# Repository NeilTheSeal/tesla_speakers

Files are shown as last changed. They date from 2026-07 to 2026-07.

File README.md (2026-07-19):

# Tesla Model 3 Rear-Cabin Speaker

A parametric, 3D-printable sealed speaker enclosure for the rear cabin floor behind the center console of a Tesla Model 3. The cabinet is modeled in [CodeCAD](https://codecad.xyz/) with Lua and designed for active DSP (woofer channel) and passive crossover (midrange/tweeter channel) use with the vehicle's 65W/4Ω amplifier outputs.

**Current System:** 3-driver mono loudspeaker (woofer + midrange + tweeter) with sealed chambers and removable, gasketed service panels for future modifications.

**Current Phase:** Fabrication readiness: inventory delivered hardware, commission the printer, and verify physical dimensions before revising or printing the enclosure.

For comprehensive project documentation, see the `docs/` folder: [PROJECT.md](docs/PROJECT.md), [REQUIREMENTS.md](docs/REQUIREMENTS.md), [WORK_HISTORY.md](docs/WORK_HISTORY.md), and [HARDWARE_SPECS.md](docs/HARDWARE_SPECS.md).

## Renders

Generated cabinet model:

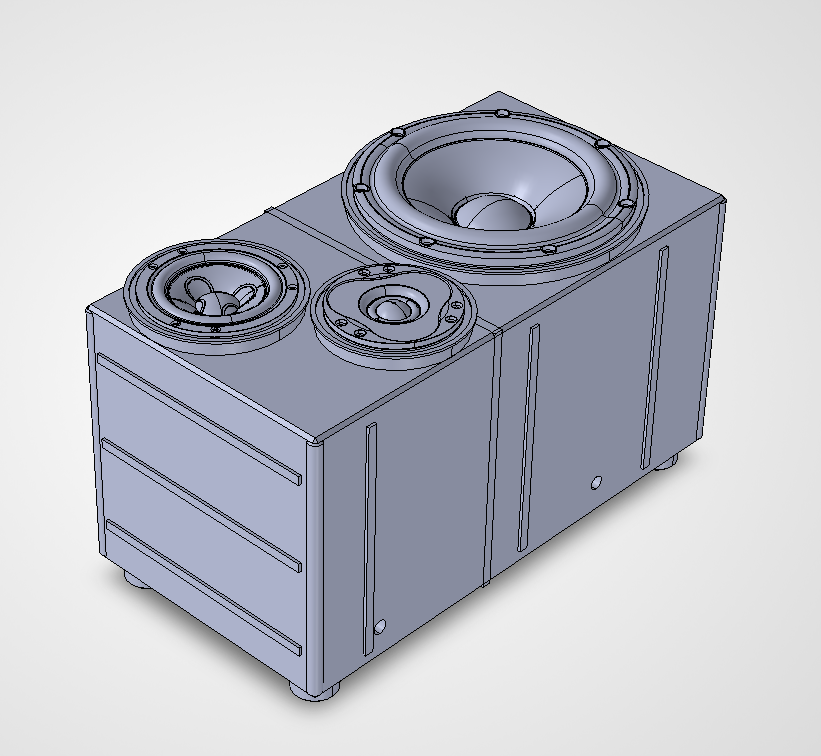
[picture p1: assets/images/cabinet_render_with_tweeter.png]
Cabinet render


## Drivers

| Position | Driver | Impedance | Status |
| --- | --- | --- | --- |
| Woofer | Scan-Speak Revelator 22W/4851T00 | 4 Ω | Purchased |
| Midrange | Scan-Speak Illuminator 12MU/4731T00 | 4 Ω | Purchased |
| Tweeter  | Scan-Speak Illuminator D3004/662000 | 4 Ω | Working selection (verification pending) |

**Driver mounting:** Cutout sizes and frame dimensions are encoded in [parts/part.lua](parts/part.lua) and must be verified against physical drivers before a full-size print.

## Current Design

**System Architecture:**

- **Amplifier channel 1** → DSP low-pass + tuning → Woofer (dedicated sealed chamber)
- **Amplifier channel 2** → DSP high-pass + tuning → Passive midrange/tweeter crossover
  - Midrange and tweeter share the second amplifier output through a passive network
  - Crossover frequency: ~2.5 kHz (provisional, subject to measurement)

**Enclosure:**

- Sealed, two-chamber cabinet (separate woofer and midrange volumes) with isolated tweeter rear chamber
- Primarily one-piece large-format 3D-printed structural shell
- Removable, gasketed side-access panels for service access and future modifications
- Internal divider isolates midrange from woofer back-wave pressure
- Nominal dimensions: 241.3 mm (width) × 410 mm (length) × 220 mm (height)
- Generated STL envelope: 246.3 mm × 415 mm × 253.05 mm (preliminary)
- Preliminary chamber volumes: woofer ~12.04 L, midrange ~5.70 L (awaiting detailed analysis)

**Structural Features:**

- 8 mm enclosure walls with internal bracing and reinforcement ribs
- 12 mm raised driver baffles with trim rings
- Internal woofer chamber window brace with rounded opening
- Two 12.5 mm side-wall wire pass-throughs (sized for PG7 cable glands)
- Four Sorbothane-ready isolation feet (38.1 mm diameter, 19.05 mm tall)
- Flared foot collars and underside X cross-bracing for stiffness
- Low-relief exterior detail elements

**Current Milestone:** Complete one documented printer calibration print, then verify the physical drivers and vehicle envelope. The removable, gasketed side panel remains the next focused CAD revision; no full enclosure print should begin until those gates and feature coupons pass.

## Files

- `assets/` — Cabinet and assembly renders, reference CAD models
- `docs/` — Project documentation (PROJECT.md, REQUIREMENTS.md, WORK_HISTORY.md, HARDWARE_SPECS.md)
- `parts/` — Parametric CodeCAD model (part.lua)
- `scripts/` — Utility scripts
- `generated/` — Build outputs (STL and STEP files)
- `.claude/` — Claude Code configuration and project instructions (CLAUDE.md)
- `.obsidian/` — Obsidian vault configuration and settings
- `.luarc.json` — Lua language server configuration for IDE support
- `project.json` — CodeCAD project definition
- `AGENTS.md` — AI agent coordination and workflow documentation
- `imgui.ini` — CodeCAD ImGui layout and window state

## Build

This project uses millimeters. Install CodeCAD, then run these commands from
the repository root:

```bash
# Open CodeCAD's live viewer and reload the model on each save.
ccad live

# Export STL and STEP files to generated/.
ccad build

# Check the CodeCAD installation if needed.
ccad doctor
```

## Parameters

The editable values are grouped at the top of
[parts/part.lua](parts/part.lua). The most useful groups are:

- **Cabinet:** width, length, height, wall thickness, divider location, and
  window-brace dimensions.
- **Drivers:** cutout sizes, frame sizes, bolt geometry, and individual X/Y
  positions.
- **Isolation:** foot dimensions, collar flare, Sorbothane pocket, and bottom
  cross-brace dimensions.
- **Finish:** baffle trim rings, exterior rails, corner bumpers, and the
  recessed monogram badge.

All driver-related position changes move the baffle, main cutout, and its bolt
pattern together.

## Print And Assembly Notes

- Use this PLA+ design as a functional prototype. For sustained in-car use,
  prefer a higher-temperature material such as ASA, PETG, or another material
  appropriate to the vehicle's temperature range.
- Use closed-cell gasket tape under the driver frames and seal the wire exits
  with suitable grommets and flexible sealant. A sealed cabinet is sensitive to
  small air leaks.
- Fit 1.0625 in diameter by 0.25 in thick Sorbothane discs into the underside
  foot pockets. Select the Sorbothane durometer for the fully loaded cabinet
  weight and intended compression range.
- Line the woofer chamber walls with damping material. Add stuffing gradually
  after measurement; keep it clear of the woofer basket and vent.
- Line and moderately fill the isolated midrange chamber with suitable acoustic
  absorption to reduce internal reflections.
- The model includes structural braces, but print orientation, perimeter count,
  material choice, and infill should be chosen for a rigid, airtight enclosure.

## Status

This is a proof-of-concept enclosure intended for active tuning and in-car
measurement. Validate the final response, crossover settings, sealing, and
mechanical fit with the actual drivers before treating it as a permanent
installation. The printer, speakers, filament, tools, and related supplies have
been reported as delivered, but exact inventory and commissioning results are
not yet recorded. The immediate sequence is inventory → printer calibration →
physical driver and vehicle checks → focused feature coupons → full-print review.

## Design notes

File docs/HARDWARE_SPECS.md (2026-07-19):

---
document: HARDWARE_SPECS
project: Tesla Rear-Cabin Speaker
status: Reference
version: 0.1
last_updated: 2026-07-18
---

# Tesla Rear-Cabin Speaker - Hardware Specifications

## 1. Purpose and source status

This file is a convenient Markdown transcription of manufacturer specifications for the three intended Scan-Speak drivers. It is a reference, not a replacement for the original datasheets or physical measurements.

Primary sources:

- [Scan-Speak Illuminator 12MU/4731T00 datasheet](../assets/datasheets/12mu-4731t00.pdf)
- [Scan-Speak Revelator 22W/4851T00 datasheet](../assets/datasheets/22w-4851t00.pdf)
- [Scan-Speak Illuminator D3004/662000 datasheet](../assets/datasheets/d3004-662000.pdf)

Important interpretation rules:

- Manufacturer values describe representative production units under the manufacturer's test conditions.
- Nominal impedance is not a fixed resistance; actual impedance varies with frequency.
- Manufacturer response curves are useful design references but do not represent the response of these particular units in the project enclosure or vehicle.
- Manufacturer enclosure recommendations are examples, not automatically the correct alignments for this project.
- Physical driver dimensions, DC resistance, mounted response, and impedance shall still be measured or verified before the design is frozen.

## 2. Driver summary

| Role | Driver | Nominal impedance | Sensitivity (2.83 V/1 m) | Recommended operating range | Linear excursion |
| --- | --- | ---: | ---: | ---: | ---: |
| Midrange | Scan-Speak Illuminator 12MU/4731T00 | 4 ohm | 90 dB | 100-10,000 Hz | +/- 3.5 mm |
| Woofer | Scan-Speak Revelator 22W/4851T00 | 4 ohm | 89 dB | fs-3,000 Hz | +/- 9 mm |
| Tweeter  | Scan-Speak Illuminator D3004/662000 | 4 ohm | 91.5 dB | 2,500-30,000 Hz | +/- 0.2 mm |

The sensitivity figures are not sufficient by themselves to set final relative levels. Baffle geometry, measurement distance, crossover losses, frequency-dependent response, and the vehicle installation will affect the required DSP and passive-network attenuation.

---

# 3. Scan-Speak Illuminator 12MU/4731T00 midrange

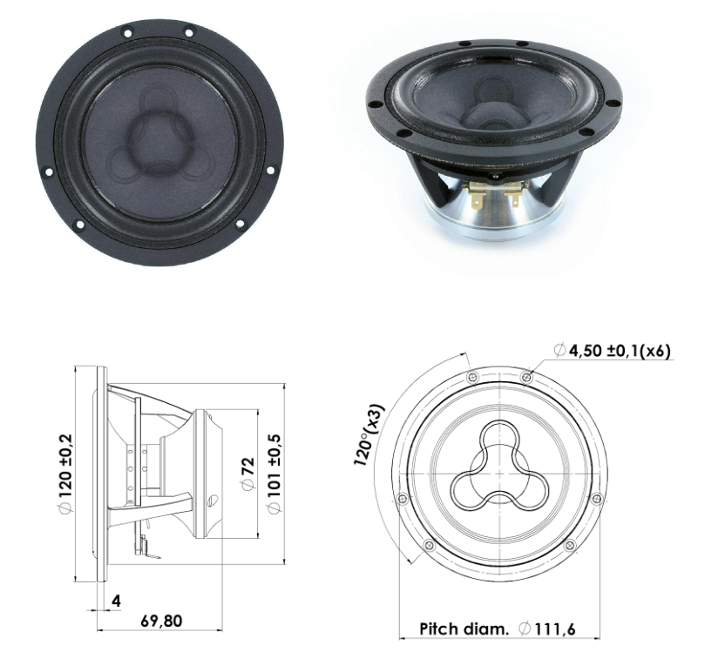
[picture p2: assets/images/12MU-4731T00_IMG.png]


## 3.1 Thiele-Small parameters

| Parameter | Symbol | Value |
| --- | --- | ---: |
| Resonance frequency | fs | 64 Hz |
| Mechanical Q factor | Qms | 3.64 |
| Electrical Q factor | Qes | 0.26 |
| Total Q factor | Qts | 0.24 |
| Force factor | Bl | 5.1 Tm |
| Mechanical resistance | Rms | 0.60 kg/s |
| Moving mass | Mms | 5.4 g |
| Compliance | Cms | 1.15 mm/N |
| Effective diaphragm diameter | D | 86 mm |
| Effective piston area | Sd | 58 cm^2 |
| Equivalent compliance volume | Vas | 5.4 L |
| Sensitivity | - | 90 dB at 2.83 V/1 m |

## 3.2 Mechanical data

| Parameter | Value |
| --- | ---: |
| Voice-coil diameter | 32 mm |
| Voice-coil height | 6 mm |
| Voice-coil layers | 4 |
| Gap height | 13 mm |
| Linear excursion | +/- 3.5 mm |
| Maximum mechanical excursion |  +/- 10 mm |
| Unit weight | 0.8 kg |
| Cabinet displacement volume  | 0.14 L |

## 3.3 Electrical data

| Parameter | Symbol | Value |
| --- | --- | ---: |
| Nominal impedance | Zn | 4 ohm |
| Minimum impedance | Zmin |  4.3 ohm |
| Maximum impedance | Zo | 46.5 ohm |
| DC resistance | Re |  3.1 ohm |
| Voice-coil inductance | Le |  0.11 mH |

## 3.4 Power handling

| Test or condition | Value |
| --- | ---: |
| 100-hour RMS noise test, IEC 18.4 | 80 W |
| Long-term maximum power, IEC 18.2 | 150 W |
| Manufacturer test crossover | Second-order Butterworth high-pass at 200 Hz |

The power ratings are tied to the manufacturer's stated test conditions. They do not mean the driver can safely dissipate those powers with arbitrary signals, enclosure loading, or filters.

## 3.5 Manufacturer-listed key features

- Under-hung neodymium motor design
- Patented Symmetrical Drive (SD-3)
- One-piece cone and dust cap
- Low-loss linear suspension
- Very wide 100-10,000 Hz frequency response
- 90 dB output at 2.83 V

## 3.6 Manufacturer recommendations

| Item | Recommendation |
| --- | --- |
| Operating frequency range | 100-10,000 Hz |
| Closed box example | Vbox = 0.9 L; f(-3 dB) = 172 Hz |
| Vented box example | Vbox = 1.5 L; fb = 99 Hz; f(-3 dB) = 119 Hz |

## 3.7 Manufacturer response and impedance curves

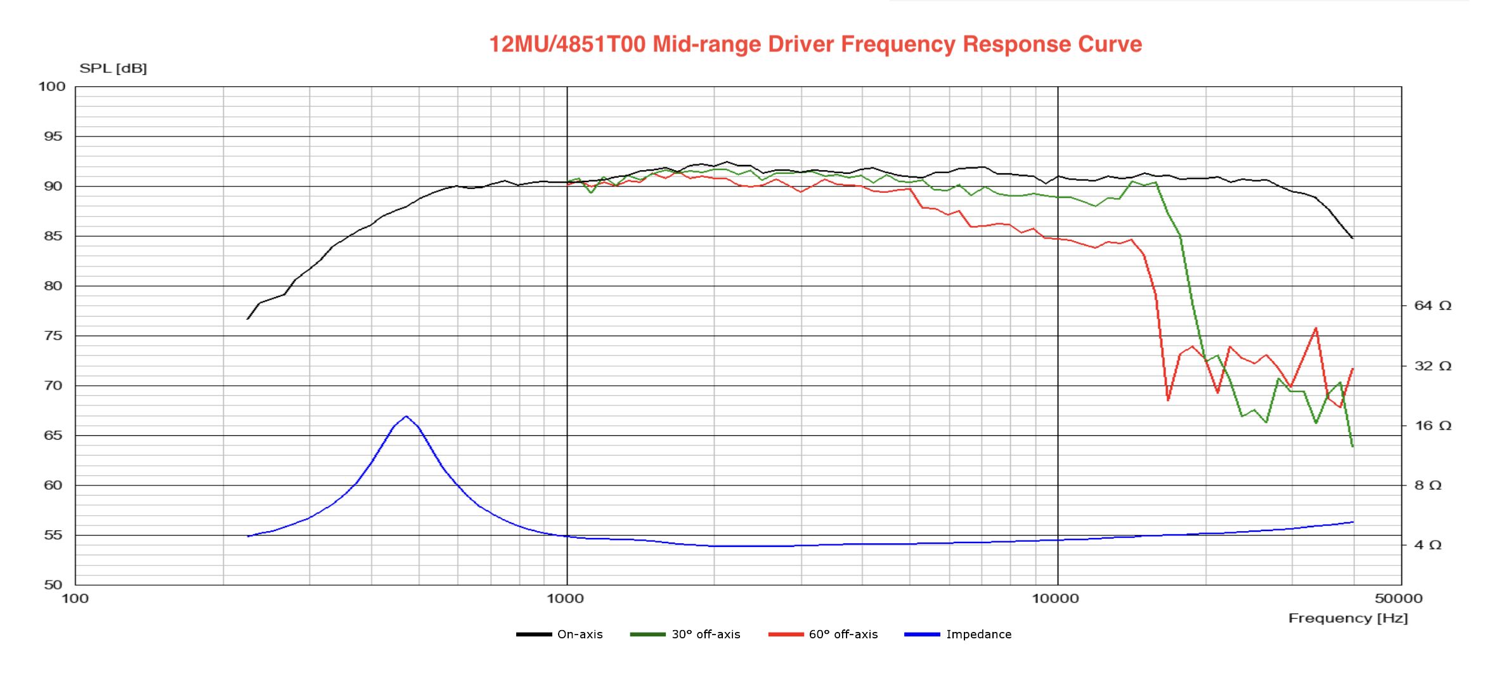
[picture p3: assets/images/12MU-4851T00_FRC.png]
12MU/4731T00 manufacturer response and impedance curves


Qualitative reading only:

- The on-axis response is broadly near 90 dB through much of the midrange and remains extended well above the intended approximate 2.5 kHz midrange/tweeter transition.
- The 30-degree and especially 60-degree curves fall progressively below the on-axis curve as frequency rises, showing the expected narrowing directivity of a cone driver.
- The impedance peak near the driver's resonance and the rising high-frequency impedance confirm that the driver cannot be treated as an ideal 4-ohm resistor during passive-crossover design.
- The smooth response around the provisional crossover region makes approximately 2.5 kHz a plausible starting region, but the final acoustic target must come from measurements in the actual baffle.

---

# 4. Scan-Speak Revelator 22W/4851T00 woofer

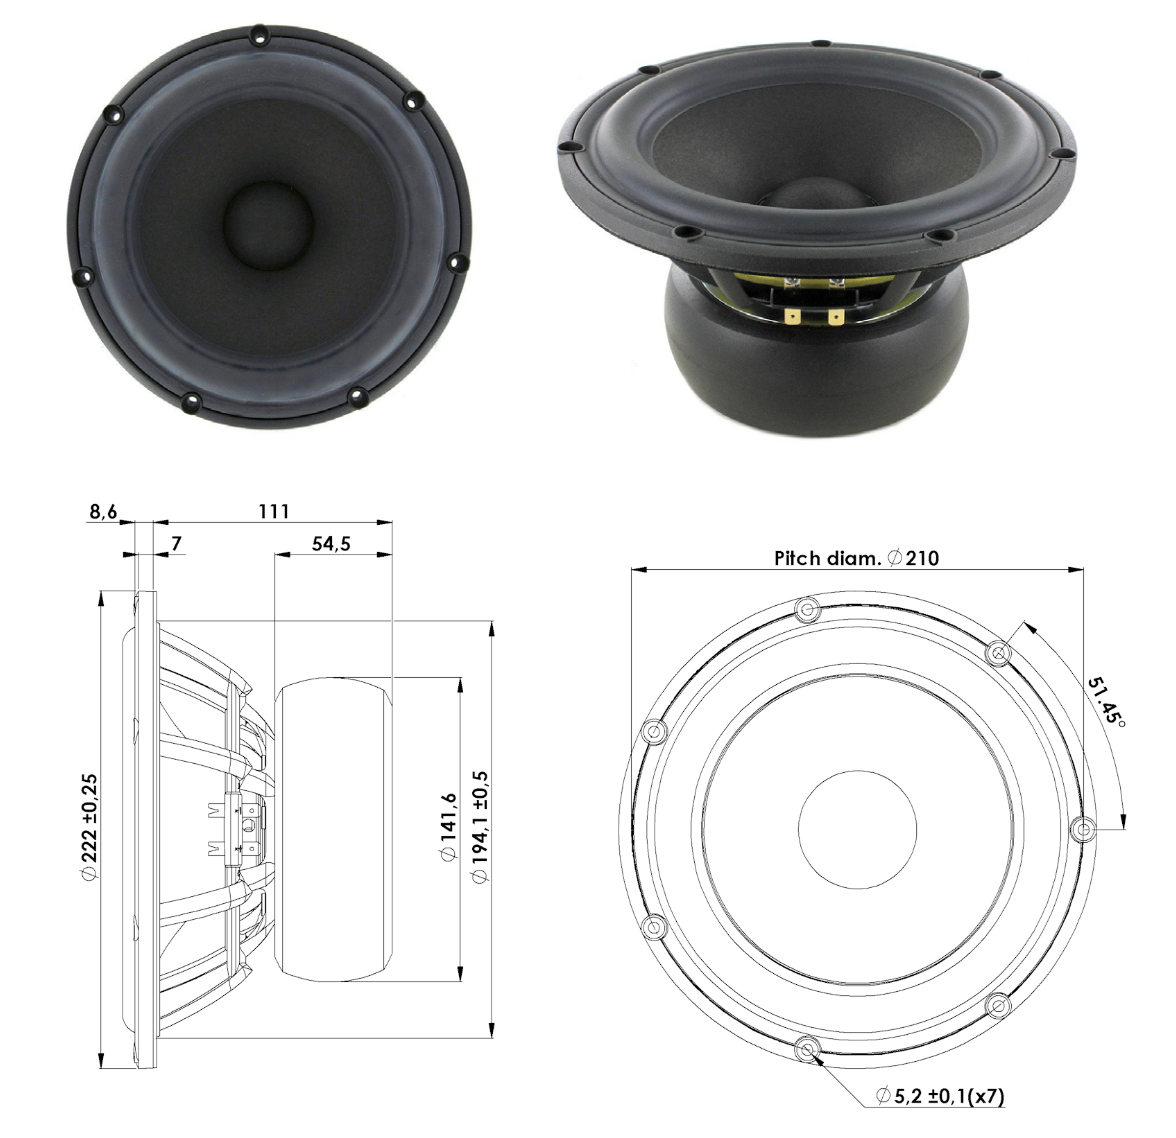
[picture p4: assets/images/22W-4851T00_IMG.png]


## 4.1 Thiele-Small parameters

| Parameter | Symbol | Value |
| --- | --- | ---: |
| Resonance frequency | fs | 21 Hz |
| Mechanical Q factor | Qms | 5.20 |
| Electrical Q factor | Qes | 0.23 |
| Total Q factor | Qts | 0.22 |
| Force factor | Bl | 8.2 Tm |
| Mechanical resistance | Rms | 0.81 kg/s |
| Moving mass | Mms | 32.5 g |
| Compliance | Cms | 1.85 mm/N |
| Effective diaphragm diameter | D | 167 mm |
| Effective piston area | Sd | 220 cm^2 |
| Equivalent compliance volume | Vas | 126 L |
| Sensitivity | - | 89 dB at 2.83 V/1 m |

## 4.2 Mechanical data

| Parameter | Value |
| --- | ---: |
| Voice-coil diameter | 50 mm |
| Voice-coil height | 24 mm |
| Voice-coil layers | 2 |
| Gap height | 6 mm |
| Linear excursion |  +/- 9 mm |
| Maximum mechanical excursion | +/- 14 mm |
| Unit weight | 3.6 kg |
| Cabinet displacement volume  | 1.04 L |

## 4.3 Electrical data

| Parameter | Symbol | Value |
| --- | --- | ---: |
| Nominal impedance | Zn | 4 ohm |
| Minimum impedance | Zmin |  4.5 ohm |
| Maximum impedance | Zo | 87.4 ohm |
| DC resistance | Re |  3.7 ohm |
| Voice-coil inductance | Le | 0.3 mH |

## 4.4 Power handling

| Test or condition | Value |
| --- | ----: |
| 100-hour RMS noise test, IEC 18.4 |  80 W |
| Long-term maximum power, IEC 18.2 | 200 W |
| Manufacturer test crossover |  None |

The power ratings are tied to the manufacturer's stated test conditions. Safe output in this project also depends on enclosure volume, excursion, signal spectrum, DSP filtering, amplifier clipping, and thermal conditions.

## 4.5 Manufacturer-listed key features

- Patented Symmetrical Drive motor design
- Rigid paper cone
- Low-loss linear suspension
- Low-damping SBR rubber surround
- Die-cast aluminum chassis vented below the spider
- Ferrite magnet system with rubber boot

## 4.6 Manufacturer recommendations

| Item | Recommendation |
| --- | --- |
| Operating frequency range | fs-3,000 Hz |
| Closed box example | Vbox = 16 L; f(-3 dB) = 62 Hz |
| Vented box example | Vbox = 22 L; fb = 36 Hz; f(-3 dB) = 45 Hz |

## 4.7 Manufacturer response and impedance curves

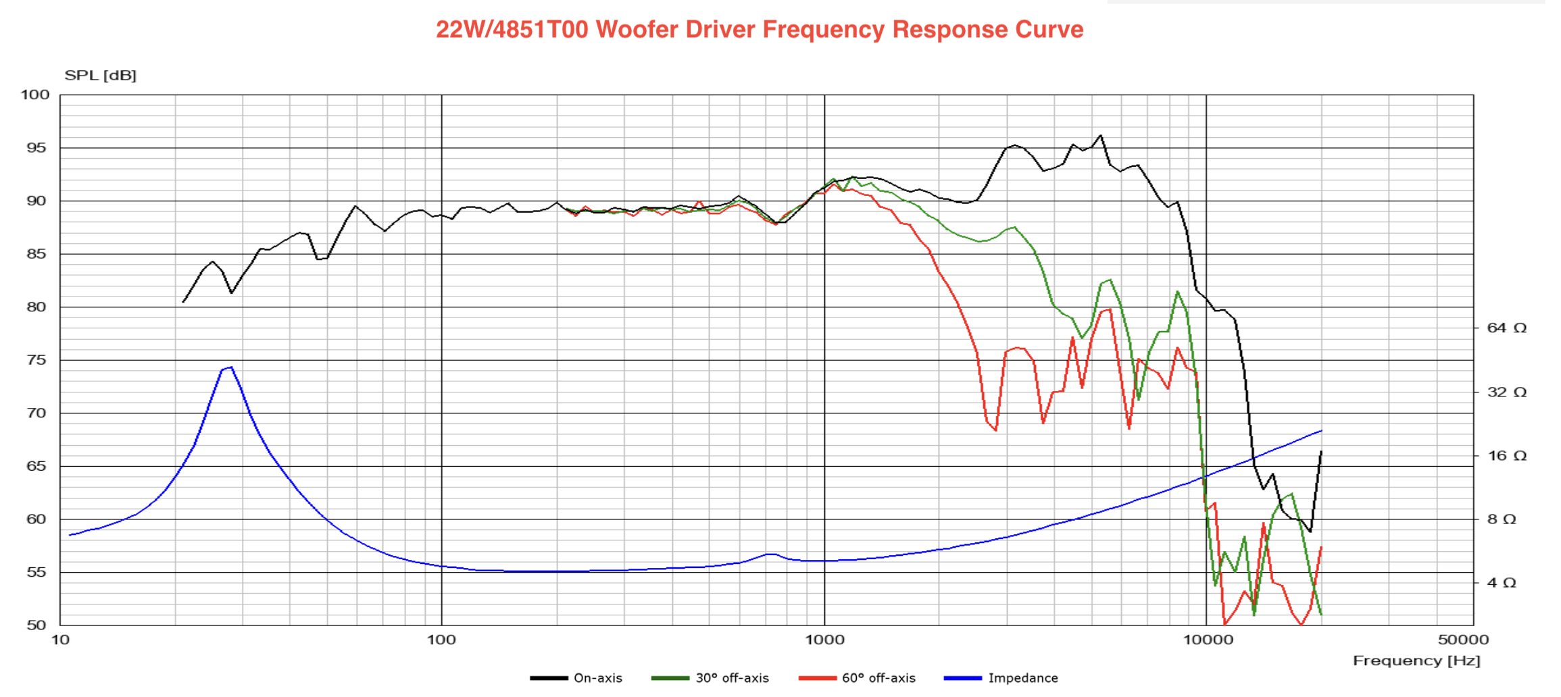
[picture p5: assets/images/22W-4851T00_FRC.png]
22W/4851T00 manufacturer response and impedance curves


Qualitative reading only:

- The on-axis response is broadly near the stated sensitivity through much of the low and middle frequency range.
- Stronger peaks and irregularities appear in the several-kilohertz region, while off-axis output narrows substantially as frequency increases. This supports keeping the woofer-to-midrange transition well below that region.
- The current project range of roughly 200-500 Hz for DSP crossover evaluation is acoustically conservative relative to the upper-frequency irregularities shown here.
- The resonance peak and rising inductive impedance reinforce the need to use measured impedance and modeled enclosure loading rather than a fixed 4-ohm assumption.

---

# 5. Scan-Speak Illuminator D3004/662000 tweeter

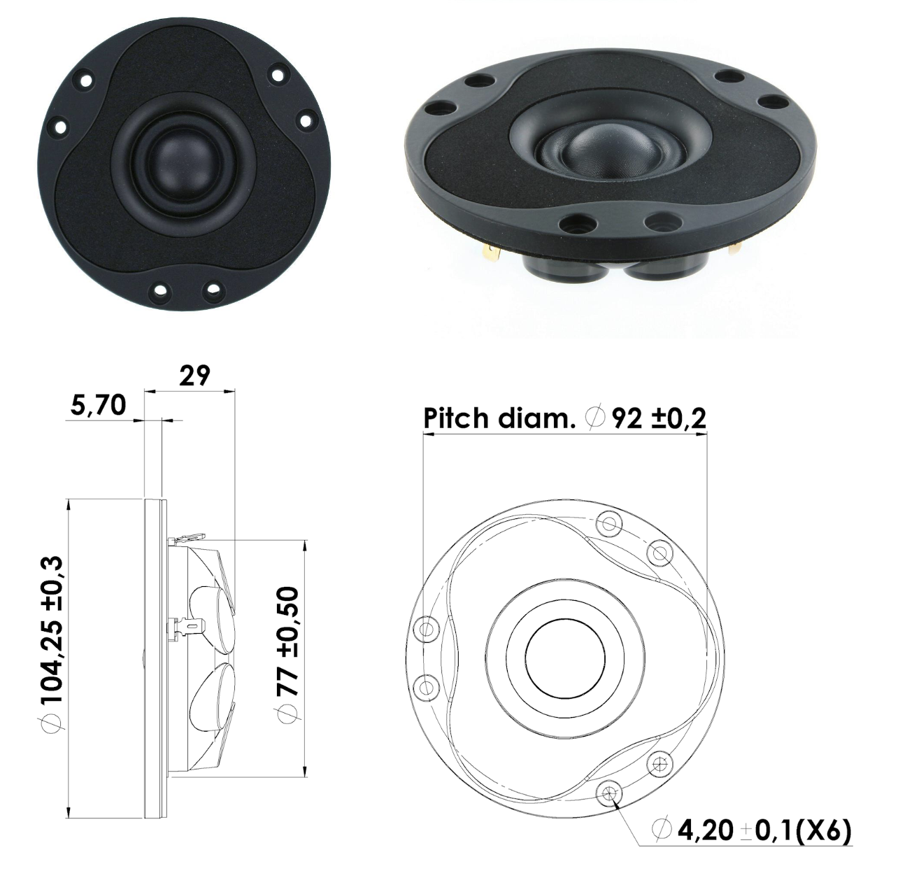
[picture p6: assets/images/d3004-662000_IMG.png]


## 5.1 Thiele-Small parameters

| Parameter | Symbol | Value |
| --- | --- | ---: |
| Resonance frequency | fs | 500 Hz |
| Mechanical Q factor | Qms | 3.79 |
| Electrical Q factor | Qes | 0.62 |
| Total Q factor | Qts | 0.54 |
| Force factor | Bl | 2.3 Tm |
| Mechanical resistance | Rms | 0.29 kg/s |
| Moving mass | Mms | 0.35 g |
| Compliance | Cms | 0.29 mm/N |
| Effective diaphragm diameter | D | 30 mm |
| Effective piston area | Sd | 7 cm^2 |
| Equivalent compliance volume | Vas | 0.02 L |
| Sensitivity | - | 91.5 dB at 2.83 V/1 m |

## 5.2 Mechanical data

| Parameter | Value |
| --- | ---: |
| Voice-coil diameter | 26 mm |
| Voice-coil height | 2.0 mm |
| Voice-coil layers | 2 |
| Gap height | 2.5 mm |
| Linear excursion | +/- 0.2 mm |
| Maximum mechanical excursion | +/- 1.6 mm |
| Unit weight | 0.3 kg |
| Cabinet displacement volume  | 0.12 L |

## 5.3 Electrical data

| Parameter | Symbol | Value |
| --- | --- | ---: |
| Nominal impedance | Zn | 4 ohm |
| Minimum impedance | Zmin |  3.9 ohm |
| Maximum impedance | Zo | 21.2 ohm |
| DC resistance | Re |  3.0 ohm |
| Voice-coil inductance | Le |  0.03 mH |

## 5.4 Power handling

| Test or condition | Value |
| --- | ---: |
| 100-hour RMS noise test, IEC 18.4 | 90 W |
| Long-term maximum power, IEC 18.2 | 150 W |
| Manufacturer test crossover | Second-order Butterworth high-pass at 2.5 kHz |

The published power ratings presume the stated filtering and manufacturer test conditions. The tweeter shall not be connected directly to an unfiltered full-range amplifier output.

## 5.5 Manufacturer-listed key features

- 1-inch textile-dome diaphragm
- Large-roll surround for wide dispersion
- Patented Symmetrical Drive (SD-2) motor
- AirCirc motor design with six neodymium magnets
- Diffraction-damping rubber front
- Die-cast, rubber-painted aluminum faceplate

## 5.6 Manufacturer recommendations

| Item | Recommendation  |
| --- | --- |
| Operating frequency range | 2,500-30,000 Hz |
| Closed box example | Not applicable  |
| Vented box example | Not applicable  |

## 5.7 Manufacturer response and impedance curves

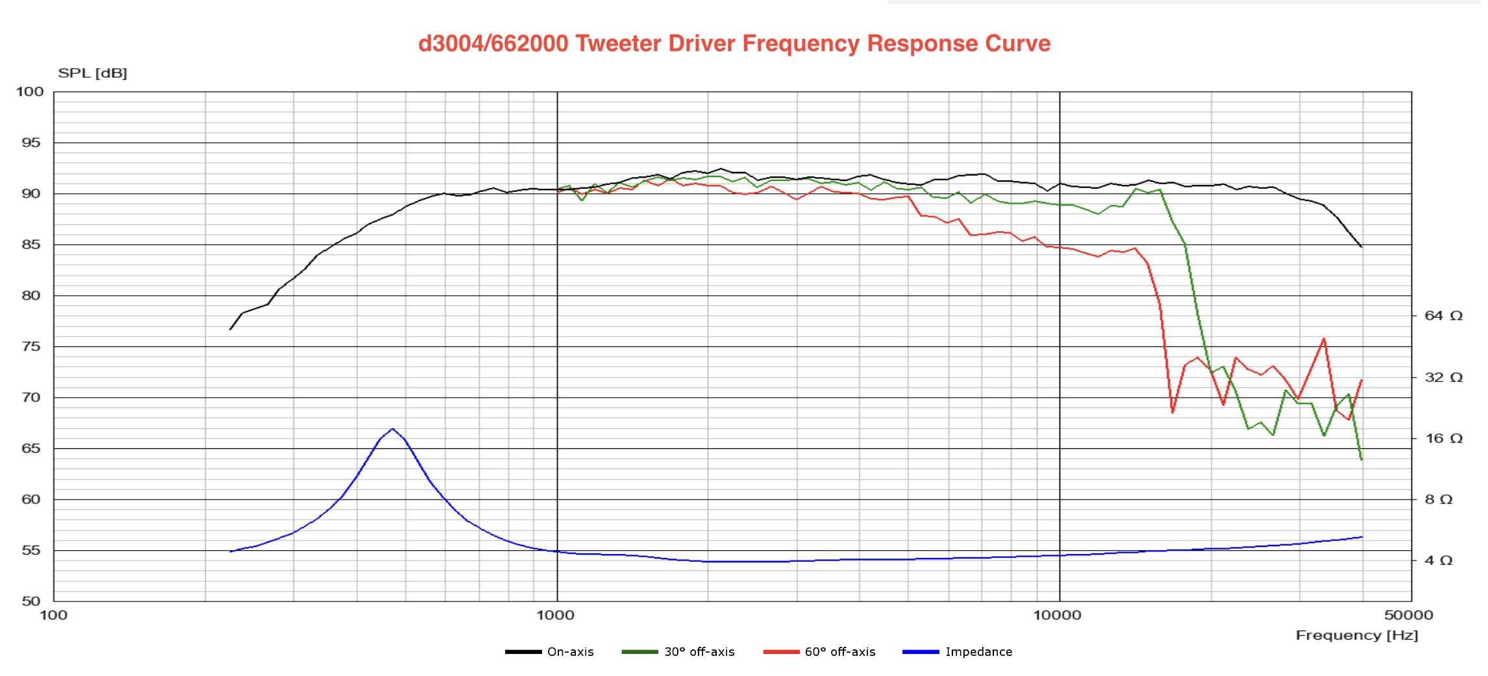
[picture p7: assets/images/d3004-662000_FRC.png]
D3004/662000 manufacturer response and impedance curves


Qualitative reading only:

- The on-axis response is broadly level through most of the intended high-frequency band before rolling off in the top octave.
- The 30-degree and 60-degree curves show progressively reduced high-frequency output off axis. Tweeter aiming and listening-position geometry will therefore matter in the vehicle.
- The prominent impedance peak near 500 Hz matches the stated resonance region.
- A 2.5 kHz crossover is approximately five times the nominal resonance frequency and matches the manufacturer's stated test filter, but the project still requires a measurement-derived acoustic crossover and safe passive protection.

---

# 6. Transcription and naming notes

- The user-provided woofer transcription listed Qes as `0.20`; the rendered manufacturer PDF shows `0.23`.
- The woofer Cms value was initially read from the rendered PDF as `0.85 mm/N`; subsequent user verification established the correct value as `1.85 mm/N`.
- The user-provided midrange transcription rounded Le to `0.1 mH`; the rendered manufacturer PDF shows `0.11 mH`.
- Scan-Speak product naming appears in both compact and hyphenated forms. These are not always consistent on the Scan-Speak website, but can be treated as equivalent. This document uses the compact datasheet model names `12MU/4731T00`, `22W/4851T00`, and `D3004/662000` as canonical identifiers.
- The frequency-response PNGs are convenient crops for human reference. The original PDFs remain the primary manufacturer sources.

# 7. Project implications

These specifications reinforce, but do not newly freeze, the current architecture:

- The woofer-to-midrange transition should remain in DSP so it can be tuned without a large low-frequency passive network.
- The midrange/tweeter passive crossover should be designed from mounted acoustic response and impedance measurements, with approximately 2.5 kHz remaining a provisional starting region.
- The current approximately 5.70 L gross midrange chamber is much larger than the manufacturer's 0.9 L closed-box example and requires deliberate revision or validation.
- The current approximately 12.04 L gross woofer chamber is smaller than the manufacturer's 16 L closed-box example and requires sealed-alignment modeling using final net volume.
- Published power-handling values do not supersede the project's conservative commissioning, filtering, impedance, and limiter requirements.

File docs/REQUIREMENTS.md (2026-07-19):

---
document: REQUIREMENTS
project: Tesla Rear-Cabin Speaker
status: Draft
version: 0.1
last_updated: 2026-07-18
---

# Tesla Rear-Cabin Speaker — Requirements

## 1. Purpose

This document defines the current requirements for the Tesla rear-cabin speaker project.

It is the detailed source of truth for the constraints the design must satisfy. It should be read together with:

- `PROJECT.md` for the high-level project vision and architecture
- `WORK_HISTORY.md` for completed work, test results, decisions, and the immediate next task

This file should describe **what the system must do or satisfy**, not provide a chronological record of work.

Requirements are expected to evolve as vehicle measurements, driver data, enclosure simulations, acoustic measurements, and prototype results become available. Changes should be made deliberately and recorded in Git.

---

## 2. Requirement Conventions

### 2.1 Priority

- **MUST** — Required for the relevant prototype or release to be accepted
- **SHOULD** — Strongly preferred unless there is a documented reason not to comply
- **MAY** — Optional or desirable
- **DEFERRED** — Intentionally excluded from the current prototype

### 2.2 Status

- **Accepted** — The requirement is currently approved
- **Provisional** — The requirement is being used, but its value or wording may change
- **TBD** — A requirement exists, but a value or decision is not yet established
- **Deferred** — Not required for the first complete prototype
- **Superseded** — Replaced by a later requirement or decision

### 2.3 Verification Methods

- **Inspection** — Visual or physical inspection
- **Measurement** — Direct dimensional, electrical, thermal, or acoustic measurement
- **Test** — Functional operation under defined conditions
- **Analysis** — CAD, simulation, calculation, or data review
- **Demonstration** — Successful use in the intended environment
- **Document review** — Confirmation against project documentation or manufacturer data

### 2.4 Requirement Management Rules

1. Each requirement should have a stable identifier.
2. Existing identifiers should not be reused for unrelated requirements.
3. Changed values should be committed to Git with a brief reason.
4. A requirement should not be marked verified without evidence.
5. Unknown values should remain `TBD`; AI tools should not invent values to make the document appear complete.
6. Measured data should override assumptions and generic calculator outputs.
7. When requirements conflict, safety and driver protection take priority, followed by vehicle fit, acoustic performance, serviceability, cost, and appearance.

---

## 3. Scope and System Boundary

### SYS-001 — Intended installation

- **Priority:** MUST
- **Status:** Accepted
- **Requirement:** The first complete prototype shall operate as a single mono loudspeaker located on the rear floor behind the center console of a Tesla Model 3.
- **Verification:** Demonstration and inspection

### SYS-002 — Driver complement

- **Priority:** MUST
- **Status:** Accepted
- **Requirement:** The system shall use one woofer, one dedicated midrange, and one tweeter.
- **Verification:** Inspection

### SYS-003 — Selected woofer

- **Priority:** MUST
- **Status:** Accepted
- **Requirement:** The first prototype shall use the Scan-Speak Revelator 22W/4851T00 4-ohm woofer unless a documented compatibility or packaging problem requires replacement.
- **Verification:** Inspection and document review

### SYS-004 — Selected midrange

- **Priority:** MUST
- **Status:** Accepted
- **Requirement:** The first prototype shall use the Scan-Speak Illuminator 12MU/4731T00 4-ohm midrange unless a documented compatibility or packaging problem requires replacement.
- **Verification:** Inspection and document review

### SYS-005 — Tweeter selection

- **Priority:** MUST
- **Status:** Provisional (current working selection)
- **Current selection:** Scan-Speak Illuminator D3004/662000, 4 ohm
- **Provisional data:**
  - Rated impedance: 4 ohm nominal
  - Manufacturer sensitivity: ~85 dB @ 1 m, 1 W (per Scan-Speak datasheet)
  - Manufacturer crossover recommendation: ~2.5 kHz with appropriate passive network
  - Baffle mount: 76.2 mm diameter frame hole, 50 mm sound aperture
  - Rear chamber requirement: Nominally sealed; manufacturer provides free-air specifications
- **Requirement:** The Scan-Speak D3004/662000 shall be used unless physical measurement, fit verification, or acoustic testing demonstrates an incompatibility or superior alternative.
- **Verification:** Physical measurement against CAD model, fit test before full enclosure print, acoustic measurement in final enclosure, crossover development
- **Note:** Physical tweeter unit verification is pending.

### SYS-006 — First-release architecture

- **Priority:** MUST
- **Status:** Accepted
- **Requirement:** The first complete prototype shall use two powered amplifier outputs with a hybrid active/passive architecture:
  - one channel dedicated to the woofer
  - one channel feeding a passive midrange/tweeter crossover
- **Verification:** Inspection and test

### SYS-007 — Mono source routing

- **Priority:** MUST
- **Status:** Provisional
- **Requirement:** Both amplifier outputs shall receive the same intended mono program mix unless measurements demonstrate that a different input mix produces a better result.
- **Verification:** DSP configuration review and test

### SYS-008 — No output-channel combining

- **Priority:** MUST
- **Status:** Accepted
- **Requirement:** The two amplifier outputs shall remain electrically isolated and shall never be tied together at their positive or negative terminals.
- **Verification:** Inspection and continuity test

### SYS-009 — Prototype emphasis

- **Priority:** MUST
- **Status:** Accepted
- **Requirement:** The first enclosure is a proof-of-concept and shall prioritize fit, safe operation, measurement access, and design learning over final cosmetic quality.
- **Verification:** Document review

### SYS-010 — Non-goals for V1

- **Priority:** DEFERRED
- **Status:** Accepted
- **Requirement:** The following are not required for the first complete prototype:
  - stereo reproduction from the custom enclosure
  - an internal power amplifier
  - wireless streaming
  - battery operation
  - final furniture-grade appearance
  - final indoor-speaker conversion
- **Verification:** Document review

---

## 4. Vehicle Packaging and Installation

### VEH-001 — Installation location

- **Priority:** MUST
- **Status:** Accepted
- **Requirement:** The enclosure shall fit on the rear center floor behind the center console.
- **Verification:** Demonstration and measurement

### VEH-002 — Available-space utilization

- **Priority:** SHOULD
- **Status:** Accepted
- **Requirement:** The enclosure should use as much acoustically useful volume as practical within the verified installation envelope.
- **Verification:** CAD analysis and vehicle fit test

### VEH-003 — Seat movement

- **Priority:** MUST
- **Status:** Provisional
- **Requirement:** The enclosure shall not prevent required front-seat movement or contact moving seat structures throughout the agreed operating range.
- **Verification:** Vehicle fit test
- **Open item:** Define the required seat-position range.

### VEH-004 — Rear passenger interference

- **Priority:** MUST
- **Status:** Provisional
- **Requirement:** The enclosure shall not create unacceptable interference with normal rear-passenger leg and foot placement.
- **Verification:** Demonstration
- **Open item:** Define whether the center rear seating position must remain usable.

### VEH-005 — HVAC clearance

- **Priority:** MUST
- **Status:** Accepted
- **Requirement:** The enclosure shall not block rear HVAC outlets or prevent normal adjustment of the rear vent controls.
- **Verification:** Inspection and demonstration

### VEH-006 — Vehicle controls and service points

- **Priority:** MUST
- **Status:** Accepted
- **Requirement:** The installation shall not obstruct required seat latches, trim removal points, service access, emergency equipment, or vehicle controls.
- **Verification:** Inspection

### VEH-007 — No permanent visible modification

- **Priority:** MUST
- **Status:** Accepted
- **Requirement:** The first prototype shall not require drilling, cutting, or permanently altering visible vehicle trim, carpet, seats, or the center console.
- **Verification:** Inspection

### VEH-008 — Reversible installation

- **Priority:** MUST
- **Status:** Accepted
- **Requirement:** The enclosure and wiring shall be removable without irreversible modification to the vehicle.
- **Verification:** Demonstration

### VEH-009 — Primary restraint

- **Priority:** MUST
- **Status:** TBD
- **Requirement:** Before normal occupied-road use, the enclosure shall have a positive mechanical restraint that prevents it from becoming a projectile during emergency braking or a collision.
- **Verification:** Inspection, analysis, and physical load test
- **Constraint:** Sorbothane pads, friction, enclosure weight, hook-and-loop material, or Dual Lock alone shall not be considered the primary crash restraint.

### VEH-010 — Existing hard points

- **Priority:** SHOULD
- **Status:** Provisional
- **Requirement:** The preferred retention method should use existing vehicle structural or seat-mounting hard points without compromising their original function.
- **Verification:** Inspection and analysis

### VEH-011 — Restraint load case

- **Priority:** MUST
- **Status:** TBD
- **Requirement:** A documented multidirectional retention load target shall be established before the restraint design is approved.
- **Verification:** Analysis and test

### VEH-012 — Rattle prevention

- **Priority:** MUST
- **Status:** Accepted
- **Requirement:** Every enclosure-to-vehicle contact surface shall be designed to avoid audible buzzes, squeaks, and rattles during normal driving and speaker operation.
- **Verification:** Road test and acoustic test

### VEH-013 — Floor protection

- **Priority:** MUST
- **Status:** Accepted
- **Requirement:** Contact surfaces shall not cut, permanently mark, or abrade the vehicle floor covering or all-weather mat during normal use.
- **Verification:** Inspection after use

### VEH-014 — Cable routing

- **Priority:** MUST
- **Status:** Accepted
- **Requirement:** Speaker wiring shall be routed and retained so that it cannot be pinched by seats, abraded by trim or rails, pulled by passengers, or create a trip hazard.
- **Verification:** Inspection and seat-movement test

---

## 5. Packaging Baseline from Current CAD

The following values describe the current prototype body and are design baselines, not yet final vehicle-envelope requirements.

### MEC-BASE-001 — Current cabinet body

- **Status:** Provisional
- **Nominal body dimensions (CAD model interior reference):**
  - body width: 9.5 in / 241.3 mm
  - body length: 410 mm
  - body height: 220 mm
  - nominal wall thickness: 8 mm
- **Generated STL envelope (preliminary, from CodeCAD Lua output):**
  - bounding X: 246.3 mm (includes wall thickness and trim)
  - bounding Y: 415 mm (length)
  - bounding Z: 253.05 mm (height varies with baffle and foot height)
  - _Note: Calculated from STL export; requires slicer verification for actual print dimensions_
- **Note:** Raised baffles, trim rings, feet, driver protrusion, grilles, fasteners, and wiring may increase the total installed envelope beyond the nominal body dimensions.

### MEC-BASE-002 — Current printer envelope and fit

- **Status:** Under Review
- **Printer build volume:** 420 × 420 × 480 mm
- **Current generated length (Y-axis):** 415 mm
- **Margin analysis:** 5 mm remaining (415 mm model + slicer clearance margin must fit within 420 mm)
- **Requirement:** The enclosure shall fit within the printer build volume with adequate slicer clearance. Actual fit must be verified with the specific slicer profile before printing.
- **Flag:** The 5 mm margin between the current 415 mm generated length and the 420 mm printer dimension is marginal. Slicer settings, nozzle offset, and bed-level variation must be verified before committing to the full print.
- **Verification:** Slicer review with actual equipment, test print verification before full-enclosure commitment
- **Alternative approach:** Removable side-access panels (see MEC-V1-PANEL) provide design flexibility if full one-piece print proves infeasible or undesirable.

### MEC-BASE-003 — Current chamber division

- **Status:** Provisional
- **Current value:**
  - divider position: Y = 270 mm
  - divider thickness: 8 mm
- **Verification:** CAD review

### MEC-BASE-004 — Current baffle geometry

- **Status:** Provisional
- **Current value:**
  - raised baffle thickness: 12 mm
  - baffle margin outside driver frame: 6 mm
  - trim ring height: 2 mm
- **Verification:** CAD review

### MEC-BASE-005 — Current feet

- **Status:** Provisional
- **Current value:**
  - foot diameter: 1.5 in / 38.1 mm
  - foot height below body: 0.75 in / 19.05 mm
  - Sorbothane pad diameter: 1.0625 in / 26.99 mm
  - Sorbothane recess depth: 0.25 in / 6.35 mm
- **Verification:** CAD review and test fit

### MEC-BASE-006 — Current driver cutouts

- **Status:** Provisional
- **Current value:**
  - woofer cutout: 194.1 mm
  - woofer frame allowance: 222 mm
  - midrange cutout: 101 mm
  - midrange frame allowance: 120 mm
- **Requirement:** These values shall be independently verified against the physical drivers and manufacturer drawings before the full enclosure is printed.
- **Verification:** Physical measurement and document review

### MEC-V1-PANEL — Removable service access panel

- **Priority:** MUST (for V1 prototype)
- **Status:** In Design
- **Requirement:** The first complete prototype shall incorporate at least one removable, gasketed access panel to allow future internal modification, tweeter integration, crossover development, and internal inspection without requiring full enclosure re-printing.
- **Panel specifications:**
  - Location: Side-mounted access panel (currently favored approach)
  - Acoustic sealing: Continuous gasket groove (rabbet joint preferred) for consistent seal without over-tightening
  - Fastening: Reusable fasteners (screws with threaded inserts or captive nuts) for multiple open/close cycles
  - Locating features: Lip or rabbet joint to ensure repeatable alignment and seal compression
  - Minimum opening: Sufficient to access crossover components and provide acoustic measurement ports
  - Validation: Acoustic leak test after gasket installation and fastening
- **Verification:** CAD review, gasket material selection, insert/nut geometry validation, acoustic leak test

---

## 6. Mechanical Enclosure Requirements

### MEC-001 — Sealed enclosure

- **Priority:** MUST
- **Status:** Accepted
- **Requirement:** The first prototype shall use sealed acoustic chambers rather than a ported or passive-radiator alignment.
- **Verification:** Inspection and leak test

### MEC-002 — Separate woofer and midrange chambers

- **Priority:** MUST
- **Status:** Accepted
- **Requirement:** The woofer and midrange shall occupy separate sealed air volumes so woofer back pressure cannot directly modulate the midrange cone.
- **Verification:** CAD review and inspection

### MEC-BASE-007 — Preliminary gross chamber volumes (derived from current CAD)

- **Status:** Provisional Analysis
- **Preliminary gross values (from CodeCAD 2-driver baseline):**
  - Woofer chamber gross: ~12.04 liters
  - Midrange chamber gross: ~5.70 liters
  - _Note: These are derived STL volume calculations and do not yet subtract driver displacement, internal bracing, divider thickness, or crossover component volume._
- **Analysis pending:**
  - Detailed subtraction of driver, brace, and crossover displacement
  - Midrange chamber sufficiency: The Scan-Speak 12MU/4731T00 manufacturer example sealed volume is ~0.9 L; the current ~5.70 L is substantially larger and requires acoustic analysis to confirm it does not introduce undesirable low-frequency resonance or impedance behavior
  - Woofer alignment: Preliminary modeling with Thiele-Small parameters from the 22W/4851T00 datasheet
- **Requirement:** Net chamber volumes shall be calculated and verified against driver requirements and acoustic targets before the divider position is frozen.
- **Verification:** CAD volume calculation, acoustic impedance modeling, measurement validation in final enclosure

### MEC-003 — Tweeter rear volume

- **Priority:** MUST
- **Status:** TBD (pending tweeter physical verification)
- **Requirement:** The tweeter installation shall comply with the selected tweeter's rear-chamber requirements. A self-contained tweeter shall not be exposed to cabinet pressure through an unintended leak.
- **Tweeter rear-chamber note:** The Scan-Speak D3004/662000 is typically specified for sealed (infinite baffle) or free-air operation; rear-chamber pressure effects shall be evaluated during crossover development and acoustic measurement.
- **Verification:** Manufacturer document review, physical measurement in actual baffle, acoustic testing

### MEC-004 — Net chamber volume calculation

- **Priority:** MUST
- **Status:** TBD
- **Requirement:** Net woofer and midrange chamber volumes shall be calculated from the final CAD model after subtracting driver, brace, divider, fastener, wiring, and crossover displacement.
- **Verification:** CAD analysis

### MEC-005 — Woofer alignment validation

- **Priority:** MUST
- **Status:** TBD
- **Requirement:** The woofer's sealed-box alignment shall be modeled using verified driver parameters and the calculated net volume before the design is frozen.
- **Verification:** Analysis

### MEC-006 — Midrange chamber suitability

- **Priority:** MUST
- **Status:** TBD
- **Requirement:** The midrange chamber volume and damping shall be selected to avoid an objectionable low-frequency impedance or acoustic resonance within the intended operating band.
- **Verification:** Analysis and measurement

### MEC-007 — Wall stiffness

- **Priority:** MUST
- **Status:** Accepted
- **Requirement:** Walls and baffles shall be sufficiently stiff that panel vibration does not create clearly audible coloration, buzzing, or rattling at intended output.
- **Verification:** Inspection, vibration test, and acoustic measurement

### MEC-008 — Bracing

- **Priority:** SHOULD
- **Status:** Accepted
- **Requirement:** Large opposing surfaces should be coupled with internal bracing that does not excessively obstruct airflow or consume unnecessary chamber volume.
- **Verification:** CAD review and inspection

### MEC-009 — Brace airflow

- **Priority:** MUST
- **Status:** Accepted
- **Requirement:** Brace openings shall have smooth transitions and adequate area to avoid audible chuffing or creating an unintended divided acoustic volume.
- **Verification:** CAD review and test

### MEC-010 — Driver mounting rigidity

- **Priority:** MUST
- **Status:** Accepted
- **Requirement:** Each driver mounting surface shall remain flat and rigid under fastener preload and driver reaction force.
- **Verification:** Inspection and test

### MEC-011 — Driver sealing

- **Priority:** MUST
- **Status:** Accepted
- **Requirement:** Each driver frame shall seal to the baffle using a suitable compressible gasket.
- **Verification:** Inspection and leak test

### MEC-012 — Chamber penetrations

- **Priority:** MUST
- **Status:** Accepted
- **Requirement:** Wire pass-throughs, terminals, fasteners, seams, and unused holes entering a sealed chamber shall be airtight after final assembly.
- **Verification:** Inspection and leak test

### MEC-013 — Rear cutout relief

- **Priority:** SHOULD
- **Status:** Accepted
- **Requirement:** The rear of each cone-driver cutout should be relieved where practical to avoid restricting rear cone airflow while preserving adequate mounting material.
- **Verification:** CAD review

### MEC-014 — Driver clearance

- **Priority:** MUST
- **Status:** TBD
- **Requirement:** The enclosure shall provide clearance for the complete driver basket, terminals, suspension motion, magnet, mounting hardware, and attached wiring.
- **Verification:** CAD interference analysis and physical fit test

### MEC-015 — Wire clearance

- **Priority:** MUST
- **Status:** Accepted
- **Requirement:** Internal wiring shall not contact moving driver parts or rest loosely against surfaces where it can buzz.
- **Verification:** Inspection

### MEC-016 — Damping material retention

- **Priority:** MUST
- **Status:** TBD
- **Requirement:** Any internal damping material shall be mechanically retained so it cannot contact the rear of a moving cone, block ventilation, or shift during vehicle motion.
- **Verification:** Inspection and road test

### MEC-017 — Sharp edges

- **Priority:** MUST
- **Status:** Accepted
- **Requirement:** Passenger-accessible edges and corners shall not present a cutting, snagging, or puncture hazard.
- **Verification:** Inspection

### MEC-018 — Grilles

- **Priority:** MUST
- **Status:** TBD
- **Requirement:** Drivers exposed to passenger feet or cargo shall be protected by acoustically suitable grilles capable of resisting expected incidental contact.
- **Verification:** Inspection and load test

### MEC-019 — Grille clearance

- **Priority:** MUST
- **Status:** TBD
- **Requirement:** Grilles shall maintain adequate clearance from the driver surround and cone at maximum intended excursion.
- **Verification:** CAD analysis and physical test

### MEC-020 — Mass

- **Priority:** MUST
- **Status:** TBD
- **Requirement:** The final assembled mass shall be measured and used in the restraint analysis.
- **Verification:** Measurement

---

## 7. Additive Manufacturing Requirements

### MFG-001 — Parametric source

- **Priority:** MUST
- **Status:** Accepted
- **Requirement:** Major enclosure dimensions, driver locations, wall thicknesses, and mounting geometry shall remain parameterized wherever practical.
- **Verification:** Code and CAD review

### MFG-002 — Source-of-truth geometry

- **Priority:** MUST
- **Status:** TBD
- **Requirement:** The project shall identify which model is authoritative when CodeCAD and SolidWorks versions coexist.
- **Verification:** Document review

### MFG-002b — Printer commissioning record

- **Priority:** MUST
- **Status:** TBD (printer delivered; commissioning not yet recorded)
- **Requirement:** Before printing enclosure-scale geometry, the printer shall complete its manufacturer-recommended assembly and calibration process and produce a documented small calibration print.
- **Record:** Printer model, nozzle size, build surface, slicer and profile, filament identity, relevant calibration settings, observed defects, and measured X/Y/Z dimensions.
- **Verification:** Inspection, measurement, and document review

### MFG-002c — Delivered-material identification

- **Priority:** MUST
- **Status:** TBD
- **Requirement:** Filament shall be identified by polymer, manufacturer, nominal diameter, and intended role before use. Material of unknown composition shall not be used for the full enclosure or road-use structural parts.
- **Verification:** Label inspection and document review

### MFG-003 — One-piece preference

- **Priority:** SHOULD
- **Status:** Provisional
- **Requirement:** The enclosure should be printable as one structural shell when this improves sealing and rigidity and remains practical within the printer envelope.
- **Verification:** CAD and slicer review

### MFG-004 — Alternative segmentation

- **Priority:** MAY
- **Status:** Accepted
- **Requirement:** The enclosure may be split into multiple printed parts if required for print reliability, serviceability, material selection, or improved geometry, provided the joints can be made rigid and airtight.
- **Verification:** CAD review and leak test

### MFG-005 — Material temperature resistance

- **Priority:** MUST
- **Status:** TBD
- **Requirement:** The road-use enclosure material shall be validated against expected parked-vehicle interior temperatures without unacceptable creep, warping, loss of fastener preload, or seal failure.
- **Verification:** Material review and thermal test

### MFG-006 — PLA restriction

- **Priority:** MUST
- **Status:** Accepted
- **Requirement:** Standard PLA shall not be used for the final road-use structural enclosure.
- **Verification:** Material inspection

### MFG-007 — Fit-prototype material

- **Priority:** MAY
- **Status:** Accepted
- **Requirement:** Lower-cost or lower-temperature material may be used for non-road fit checks, test coupons, templates, or short-duration bench prototypes when clearly labeled.
- **Verification:** Inspection

### MFG-008 — Print-process record

- **Priority:** SHOULD
- **Status:** TBD
- **Requirement:** The final print settings shall be recorded, including material, nozzle, layer height, wall count, top/bottom layers, infill, orientation, supports, and annealing or post-processing.
- **Verification:** Document review

### MFG-009 — Shell integrity

- **Priority:** MUST
- **Status:** Accepted
- **Requirement:** The print shall not contain through-gaps, delamination, cracks, or porous regions that compromise structural integrity or acoustic sealing.
- **Verification:** Inspection and leak test

### MFG-010 — Test coupons

- **Priority:** SHOULD
- **Status:** Accepted
- **Requirement:** Critical features should be validated with small test prints before committing to the full enclosure, including driver holes, inserts, gaskets, terminal mounts, grille mounts, and Sorbothane recesses.
- **Verification:** Inspection

### MFG-011 — Fastener interfaces

- **Priority:** SHOULD
- **Status:** Accepted
- **Requirement:** Frequently removed components should use threaded inserts, captive nuts, through-bolts, or another reusable interface rather than repeatedly cutting threads directly into printed plastic.
- **Verification:** Inspection

### MFG-012 — Insert installation validation

- **Priority:** MUST
- **Status:** TBD
- **Requirement:** Heat-set or press-fit insert geometry shall be validated in the selected material with test coupons before use in the full cabinet.
- **Verification:** Pull-out and torque test

### MFG-013 — Print failure containment

- **Priority:** SHOULD
- **Status:** Accepted
- **Requirement:** The model and slicer plan should minimize the probability that a late print failure destroys all major functional features.
- **Verification:** Slicer review

---

## 8. Electrical Interface Requirements

### ELEC-001 — Available outputs

- **Priority:** MUST
- **Status:** Accepted
- **Requirement:** The system shall operate from two independent amplifier outputs, each nominally capable of 65 W into 4 ohms.
- **Verification:** Amplifier configuration and document review

### ELEC-002 — Woofer channel

- **Priority:** MUST
- **Status:** Accepted
- **Requirement:** One amplifier output shall connect only to the woofer path.
- **Verification:** Wiring inspection

### ELEC-003 — Mid/tweeter channel

- **Priority:** MUST
- **Status:** Accepted
- **Requirement:** One amplifier output shall feed the passive midrange/tweeter crossover input.
- **Verification:** Wiring inspection

### ELEC-004 — Nominal load compatibility

- **Priority:** MUST
- **Status:** TBD
- **Requirement:** Each amplifier output shall see an electrical load that remains within the amplifier's safe operating range over the full audio band.
- **Verification:** Impedance measurement and amplifier document review

### ELEC-005 — Minimum impedance

- **Priority:** MUST
- **Status:** TBD
- **Requirement:** The minimum permitted impedance magnitude and phase angle shall be established from amplifier documentation or validated testing before full-power operation.
- **Verification:** Document review and measurement

### ELEC-006 — Polarity labeling

- **Priority:** MUST
- **Status:** Accepted
- **Requirement:** Every external and internal driver connection shall be clearly labeled for function and polarity.
- **Verification:** Inspection

### ELEC-007 — Serviceable external connection

- **Priority:** MUST
- **Status:** Accepted
- **Requirement:** The enclosure shall provide a secure and serviceable external connection for each amplifier channel.
- **Verification:** Inspection and connection test

### ELEC-008 — Separate input pairs

- **Priority:** MUST
- **Status:** Accepted
- **Requirement:** The woofer input and midrange/tweeter input shall use separate isolated positive/negative terminal pairs.
- **Verification:** Continuity test

### ELEC-009 — Terminal short prevention

- **Priority:** MUST
- **Status:** Accepted
- **Requirement:** Exposed terminals and internal wiring shall be arranged so normal handling cannot short either amplifier output.
- **Verification:** Inspection

### ELEC-009b — External binding-post assembly (provisional)

- **Priority:** SHOULD
- **Status:** Provisional selection (reference component obtained)
- **Current selection:** Keystone Electronics 4109 dual binding-post assembly
- **Provisional data:**
  - Two isolated dual binding-post pairs (4 posts total)
  - Screw terminal type, suitable for 16 AWG or larger wire
  - Panel-mount M4 thread and standoff M3 anchor bolts
  - Rated for speaker-level amplifier output (typical 65 W / 4 ohm = ~5 A sustained)
- **Requirement:** An external amplifier interface shall use a dual binding-post assembly suitable for speaker-level connections. The Keystone 4109 is a provisional selection pending:
  - Final CAD panel location design
  - Verification that the current chassis can accommodate one or two dual assemblies as needed
  - Testing to confirm adequate current capacity and reliable connection under automotive vibration
- **Verification:** CAD fit review, connection reliability testing under vibration, thermal testing under expected current

### ELEC-010 — Wiring current capacity

- **Priority:** MUST
- **Status:** TBD
- **Requirement:** Wire gauge, connectors, terminals, crossover traces, and solder joints shall safely carry the expected current with negligible heating and acceptable voltage drop.
- **Verification:** Analysis and thermal test

### ELEC-011 — Strain relief

- **Priority:** MUST
- **Status:** Accepted
- **Requirement:** External and internal wires shall have strain relief so pulling on a cable does not load solder joints, driver tabs, or crossover components.
- **Verification:** Inspection and pull test

### ELEC-012 — Automotive vibration resistance

- **Priority:** MUST
- **Status:** Accepted
- **Requirement:** Electrical connections and components shall remain secure under vehicle vibration and repeated thermal cycling.
- **Verification:** Road test and inspection

### ELEC-013 — Insulation and abrasion

- **Priority:** MUST
- **Status:** Accepted
- **Requirement:** Conductors shall be insulated from sharp edges, metal vehicle structure, and moving components.
- **Verification:** Inspection

### ELEC-014 — DC resistance record

- **Priority:** SHOULD
- **Status:** TBD
- **Requirement:** The DC resistance measured at each enclosure input shall be recorded before connection to the vehicle amplifier.
- **Verification:** Multimeter measurement

### ELEC-015 — Continuity preflight

- **Priority:** MUST
- **Status:** Accepted
- **Requirement:** Before first power-up, continuity shall be verified from each input to its intended driver path, and isolation shall be verified between the two amplifier inputs.
- **Verification:** Multimeter test

---

## 9. DSP and Signal-Routing Requirements

### DSP-001 — Independent output configuration

- **Priority:** MUST
- **Status:** Accepted
- **Requirement:** The amplifier shall allow independent source mixing, gain, crossover, EQ, delay, and dynamics settings for both outputs used by the enclosure.
- **Verification:** Configuration review and demonstration

### DSP-002 — Woofer low-pass

- **Priority:** MUST
- **Status:** TBD
- **Requirement:** The woofer channel shall use a DSP low-pass filter selected from measurement and integration testing.
- **Verification:** Configuration review and acoustic measurement

### DSP-003 — Upper-channel high-pass

- **Priority:** MUST
- **Status:** TBD
- **Requirement:** The midrange/tweeter channel shall use a DSP high-pass filter that protects the midrange from excessive low-frequency excursion.
- **Verification:** Configuration review and acoustic measurement

### DSP-004 — Initial woofer/mid transition range

- **Priority:** SHOULD
- **Status:** Provisional
- **Requirement:** Initial testing should evaluate the woofer-to-midrange transition within approximately 200–500 Hz.
- **Verification:** Acoustic measurement and listening test

### DSP-005 — Input normalization

- **Priority:** MUST
- **Status:** TBD
- **Requirement:** Mono input mixing shall be configured so summed source contributions do not cause unintended gain or clipping.
- **Verification:** Configuration review and signal-level test

### DSP-006 — Output gain staging

- **Priority:** MUST
- **Status:** TBD
- **Requirement:** Output gains shall be established conservatively before full-range or high-level testing.
- **Verification:** Configuration review and test

### DSP-007 — Limiting

- **Priority:** SHOULD
- **Status:** TBD
- **Requirement:** Available limiter or dynamics functions should be used to protect drivers once safe thresholds are established.
- **Verification:** Configuration review and test

### DSP-008 — Saved configurations

- **Priority:** MUST
- **Status:** TBD
- **Requirement:** DSP configurations used for measurement, development, and normal operation shall be saved with descriptive names and version identifiers.
- **Verification:** Document review

### DSP-009 — Measurement preset

- **Priority:** MUST
- **Status:** TBD
- **Requirement:** A known measurement preset shall be created that disables undocumented EQ, enhancement, dynamics, or routing behavior that would invalidate measurements.
- **Verification:** Configuration review

### DSP-010 — Polarity and delay

- **Priority:** MUST
- **Status:** TBD
- **Requirement:** Driver polarity and channel delay shall be selected from measured acoustic summation rather than assumption alone.
- **Verification:** Acoustic measurement

### DSP-011 — Final EQ

- **Priority:** MUST
- **Status:** TBD
- **Requirement:** Final equalization shall be based on the assembled system in the installed vehicle position.
- **Verification:** Acoustic measurement and listening test

---

## 10. Passive Midrange/Tweeter Crossover Requirements

### XOV-001 — Passive split

- **Priority:** MUST
- **Status:** Accepted
- **Requirement:** The second amplifier channel shall be divided passively between the midrange and tweeter.
- **Verification:** Inspection and test

### XOV-002 — Final design basis

- **Priority:** MUST
- **Status:** Accepted
- **Requirement:** The final passive crossover shall be designed from measured driver frequency-response, phase, and impedance data in the actual enclosure.
- **Verification:** Design-file review and measurement

### XOV-003 — Textbook networks

- **Priority:** MUST
- **Status:** Accepted
- **Requirement:** A generic calculator network based only on nominal 4-ohm impedance shall not be treated as the final crossover without validation.
- **Verification:** Design review

### XOV-004 — Working crossover region

- **Priority:** SHOULD
- **Status:** Provisional
- **Requirement:** The initial design target for the midrange-to-tweeter acoustic crossover should be approximately 2.5 kHz, subject to the selected tweeter, baffle geometry, directivity, and measurements.
- **Verification:** Analysis and acoustic measurement

### XOV-005 — Acoustic target

- **Priority:** MUST
- **Status:** TBD
- **Requirement:** The final acoustic crossover topology and slope shall be selected after measurement. A fourth-order Linkwitz–Riley acoustic target may be evaluated but is not mandatory.
- **Verification:** Crossover simulation and acoustic measurement

### XOV-006 — Tweeter protection

- **Priority:** MUST
- **Status:** Accepted
- **Requirement:** The tweeter path shall contain passive high-pass protection sufficient to prevent damaging low-frequency energy under normal operation and foreseeable DSP configuration errors.
- **Verification:** Circuit review, impedance analysis, and test

### XOV-007 — Development protection

- **Priority:** MUST
- **Status:** TBD
- **Requirement:** Initial tweeter testing shall use conservative level, a suitable series protection capacitor, and a known DSP high-pass before higher-power testing.
- **Verification:** Inspection and configuration review

### XOV-008 — Midrange upper-band control

- **Priority:** MUST
- **Status:** Accepted
- **Requirement:** The passive network shall attenuate the midrange sufficiently above the crossover region to avoid unacceptable overlap, breakup contribution, or interference with the tweeter.
- **Verification:** Acoustic measurement

### XOV-009 — Sensitivity matching

- **Priority:** MUST
- **Status:** TBD
- **Requirement:** The passive network shall provide any attenuation required to match tweeter level to the midrange without exceeding component power ratings.
- **Verification:** Measurement and thermal analysis

### XOV-010 — System impedance

- **Priority:** MUST
- **Status:** TBD
- **Requirement:** The completed midrange/tweeter network shall not create an unsafe low-impedance or excessively reactive load for the amplifier.
- **Verification:** Impedance measurement

### XOV-011 — Component ratings

- **Priority:** MUST
- **Status:** TBD
- **Requirement:** Capacitors, inductors, resistors, PCB traces, terminals, and wiring shall be rated for the expected voltage, current, heat dissipation, and automotive temperature environment.
- **Verification:** Component review and thermal test

### XOV-012 — Capacitor type

- **Priority:** SHOULD
- **Status:** Provisional
- **Requirement:** Signal-path capacitors should be non-polar and appropriate for loudspeaker crossover service. Final type selection shall balance size, cost, tolerance, loss, and thermal stability.
- **Verification:** Component review

### XOV-013 — Inductor placement

- **Priority:** MUST
- **Status:** Accepted
- **Requirement:** Multiple inductors shall be separated and oriented to minimize magnetic coupling.
- **Verification:** Inspection

### XOV-014 — Component retention

- **Priority:** MUST
- **Status:** Accepted
- **Requirement:** Crossover components shall be mechanically secured against vibration; solder joints shall not serve as the sole structural support.
- **Verification:** Inspection and vibration test

### XOV-015 — Crossover serviceability

- **Priority:** SHOULD
- **Status:** Accepted
- **Requirement:** The crossover should be accessible or removable without destroying the enclosure or removing permanently bonded structural parts.
- **Verification:** Demonstration

### XOV-016 — Prototype configurability

- **Priority:** SHOULD
- **Status:** TBD
- **Requirement:** During development, the crossover should allow practical substitution of capacitors, inductors, and resistors without repeated damage to the wiring or enclosure.
- **Verification:** Inspection and demonstration

### XOV-017 — Full-power authorization

- **Priority:** MUST
- **Status:** Accepted
- **Requirement:** The midrange/tweeter channel shall not be operated near maximum amplifier output until continuity, polarity, impedance, low-level response, and tweeter protection have been verified.
- **Verification:** Test record review

---

## 11. Acoustic Performance Requirements

### ACO-001 — High-frequency coverage

- **Priority:** MUST
- **Status:** TBD
- **Requirement:** The selected tweeter and final system shall provide useful on-axis output through the upper audible range without an intentional high-frequency cutoff below 20 kHz.
- **Verification:** Manufacturer data and acoustic measurement

### ACO-002 — Low-frequency target

- **Priority:** MUST
- **Status:** TBD
- **Requirement:** The required low-frequency extension and maximum output shall be established after sealed-box modeling and in-car measurement.
- **Verification:** Analysis and acoustic measurement

### ACO-003 — Full-system response target

- **Priority:** MUST
- **Status:** TBD
- **Requirement:** A numerical in-car frequency-response target and tolerance shall be defined after the first assembled measurements.
- **Verification:** Document review and measurement

### ACO-004 — Driver integration

- **Priority:** MUST
- **Status:** Accepted
- **Requirement:** The integrated system shall not contain severe crossover-region peaks, nulls, or discontinuities at the primary listening positions.
- **Verification:** Acoustic measurement

### ACO-005 — Audible distortion

- **Priority:** MUST
- **Status:** TBD
- **Requirement:** The system shall operate at the intended listening level without clearly audible mechanical distress, rubbing, bottoming, buzzing, or excessive nonlinear distortion.
- **Verification:** Listening test and measurement

### ACO-006 — Cabinet noise

- **Priority:** MUST
- **Status:** Accepted
- **Requirement:** The enclosure, grilles, terminals, crossover, wiring, and vehicle-contact points shall not produce audible rattles or buzzes at the intended operating level.
- **Verification:** Sweep test and road test

### ACO-007 — Air leaks

- **Priority:** MUST
- **Status:** Accepted
- **Requirement:** Sealed-chamber leaks shall not produce audible hissing, chuffing, or response anomalies.
- **Verification:** Low-frequency test and leak inspection

### ACO-008 — Listening-position optimization

- **Priority:** MUST
- **Status:** Accepted
- **Requirement:** Final DSP tuning shall prioritize the intended rear-cabin listening region rather than only a microphone position close to the enclosure.
- **Verification:** Multi-position measurement and listening test

### ACO-009 — Spatial consistency

- **Priority:** SHOULD
- **Status:** TBD
- **Requirement:** The system should avoid extreme tonal changes across normal rear-seat head positions.
- **Verification:** Multi-position measurement

### ACO-010 — Directivity review

- **Priority:** SHOULD
- **Status:** TBD
- **Requirement:** Midrange/tweeter spacing, orientation, and crossover selection should be evaluated for directivity and lobing in the actual installation geometry.
- **Verification:** Analysis and off-axis measurement

### ACO-011 — Reference level

- **Priority:** MUST
- **Status:** TBD
- **Requirement:** A reference listening and measurement level shall be defined before final output, distortion, and protection requirements are evaluated.
- **Verification:** SPL measurement

### ACO-012 — Maximum safe level

- **Priority:** MUST
- **Status:** TBD
- **Requirement:** A maximum normal-use DSP level or limiter threshold shall be established from driver excursion, thermal limits, amplifier capability, and measurement.
- **Verification:** Analysis and test

---

## 12. Measurement and Validation Requirements

### MEAS-001 — Individual-driver measurement

- **Priority:** MUST
- **Status:** Accepted
- **Requirement:** The woofer, midrange, and tweeter shall each be measured independently in the intended enclosure before the final crossover and DSP tuning are frozen.
- **Verification:** Measurement-file review

### MEAS-002 — Mounted-state measurement

- **Priority:** MUST
- **Status:** Accepted
- **Requirement:** Final design measurements shall be taken with the drivers mounted in the actual baffle and chambers, not only from manufacturer datasheets or free-air testing.
- **Verification:** Measurement-file review

### MEAS-003 — Known signal path

- **Priority:** MUST
- **Status:** Accepted
- **Requirement:** Every measurement shall document the amplifier channel, DSP preset, filter state, gain, microphone location, signal type, and test level.
- **Verification:** Measurement notes

### MEAS-004 — Low-level first test

- **Priority:** MUST
- **Status:** Accepted
- **Requirement:** Initial sweeps shall begin at low level and increase only after confirming correct wiring and expected response.
- **Verification:** Test procedure review

### MEAS-005 — Microphone calibration

- **Priority:** SHOULD
- **Status:** TBD
- **Requirement:** The measurement microphone's calibration file and orientation shall be used when available and recorded with the measurement setup.
- **Verification:** Software configuration review

### MEAS-006 — Acoustic software

- **Priority:** SHOULD
- **Status:** Provisional
- **Requirement:** REW or equivalent software should be used for sweep generation, response capture, timing, and comparison.
- **Verification:** Measurement-file review

### MEAS-007 — Crossover simulation

- **Priority:** SHOULD
- **Status:** Provisional
- **Requirement:** VituixCAD or equivalent software should be used to simulate the passive crossover from measured response and impedance data.
- **Verification:** Design-file review

### MEAS-008 — Impedance measurement

- **Priority:** MUST
- **Status:** TBD
- **Requirement:** Driver and completed-network impedance shall be measured before final crossover approval and full-power use.
- **Verification:** Impedance data review

### MEAS-009 — Near-field woofer measurement

- **Priority:** SHOULD
- **Status:** TBD
- **Requirement:** Near-field measurement should be used when evaluating low-frequency driver and enclosure behavior that cannot be isolated reliably with an in-car far-field measurement.
- **Verification:** Measurement-file review

### MEAS-010 — Crossover summation

- **Priority:** MUST
- **Status:** TBD
- **Requirement:** Midrange-only, tweeter-only, normal-polarity sum, and reverse-polarity sum shall be measured during crossover development.
- **Verification:** Measurement-file review

### MEAS-011 — Multi-position final measurement

- **Priority:** MUST
- **Status:** TBD
- **Requirement:** Final system evaluation shall include multiple microphone positions representative of rear passengers.
- **Verification:** Measurement-file review

### MEAS-012 — Repeatable fixtures

- **Priority:** SHOULD
- **Status:** TBD
- **Requirement:** Microphone and enclosure positions should be repeatable enough to compare revisions meaningfully.
- **Verification:** Measurement setup review

### MEAS-013 — Raw data retention

- **Priority:** MUST
- **Status:** Accepted
- **Requirement:** Raw measurement files shall be retained in the project repository or a documented linked storage location.
- **Verification:** File review

### MEAS-014 — Result interpretation

- **Priority:** MUST
- **Status:** Accepted
- **Requirement:** Smoothed plots may be used for presentation, but design decisions shall not rely only on heavily smoothed data.
- **Verification:** Measurement-file review

---

## 13. Safety and Protection Requirements

### SAFE-001 — Driver protection during development

- **Priority:** MUST
- **Status:** Accepted
- **Requirement:** Expensive drivers shall not be exposed to full amplifier power until their wiring, filtering, polarity, and load have been verified.
- **Verification:** Test procedure review

### SAFE-002 — Tweeter low-frequency protection

- **Priority:** MUST
- **Status:** Accepted
- **Requirement:** The tweeter shall never be connected directly to an unfiltered full-range amplifier output.
- **Verification:** Inspection

### SAFE-003 — Amplifier protection

- **Priority:** MUST
- **Status:** Accepted
- **Requirement:** No development configuration shall short an amplifier output, connect one output to another, or knowingly present a load below the amplifier's safe range.
- **Verification:** Continuity and impedance test

### SAFE-004 — Power-off reconfiguration

- **Priority:** MUST
- **Status:** Accepted
- **Requirement:** Wiring and passive crossover changes shall be performed with the amplifier disabled and the output de-energized.
- **Verification:** Procedure review

### SAFE-005 — Protected conductors

- **Priority:** MUST
- **Status:** Accepted
- **Requirement:** No uninsulated energized conductor shall be accessible during normal installed use.
- **Verification:** Inspection

### SAFE-006 — Flammability and heat

- **Priority:** MUST
- **Status:** TBD
- **Requirement:** Materials placed near crossover power resistors, inductors, connectors, or future electronics shall tolerate expected heat without softening, igniting, or releasing parts.
- **Verification:** Material review and thermal test

### SAFE-007 — Component spacing

- **Priority:** MUST
- **Status:** Accepted
- **Requirement:** Heat-producing crossover components shall have adequate spacing from printed plastic, damping material, wire insulation, and adhesive.
- **Verification:** Inspection and thermal test

### SAFE-008 — Passenger contact

- **Priority:** MUST
- **Status:** Accepted
- **Requirement:** Normal passenger contact shall not expose wiring, sharp hardware, hot components, or moving speaker cones.
- **Verification:** Inspection and demonstration

### SAFE-009 — Emergency removal

- **Priority:** SHOULD
- **Status:** TBD
- **Requirement:** The enclosure should be removable with ordinary hand tools without disassembling major vehicle systems.
- **Verification:** Demonstration

---

## 14. Serviceability Requirements

### SERV-001 — Driver replacement

- **Priority:** MUST
- **Status:** Accepted
- **Requirement:** Each driver shall be removable and replaceable without cutting the enclosure.
- **Verification:** Demonstration

### SERV-002 — Crossover access

- **Priority:** SHOULD
- **Status:** Accepted
- **Requirement:** The passive crossover should be accessible for inspection and component changes.
- **Verification:** Demonstration

### SERV-003 — Internal wiring access

- **Priority:** SHOULD
- **Status:** TBD
- **Requirement:** A documented method shall exist to inspect or repair internal wiring and chamber seals.
- **Verification:** Demonstration

### SERV-004 — Standard tools

- **Priority:** SHOULD
- **Status:** Accepted
- **Requirement:** Routine installation, removal, and service should use common hand tools.
- **Verification:** Demonstration

### SERV-005 — Replaceable isolation pads

- **Priority:** SHOULD
- **Status:** Accepted
- **Requirement:** Sorbothane or other floor-contact pads should be replaceable without reprinting the enclosure.
- **Verification:** Demonstration

### SERV-006 — Terminal replacement

- **Priority:** SHOULD
- **Status:** TBD
- **Requirement:** External terminals should be replaceable without destructive disassembly.
- **Verification:** Demonstration

### SERV-007 — Assembly documentation

- **Priority:** MUST
- **Status:** TBD
- **Requirement:** The final prototype shall have an assembly and wiring record sufficient to reproduce its configuration.
- **Verification:** Document review

---

## 15. Documentation and AI Workflow Requirements

### DOC-001 — Core files

- **Priority:** MUST
- **Status:** Accepted
- **Requirement:** The repository shall contain, at minimum:
  - `PROJECT.md`
  - `REQUIREMENTS.md`
  - `WORK_HISTORY.md`
- **Verification:** File review

### DOC-002 — AI reading order

- **Priority:** MUST
- **Status:** Accepted
- **Requirement:** Before proposing or implementing project changes, AI tools shall read:
  1. `PROJECT.md`
  2. `REQUIREMENTS.md`
  3. the latest relevant portion of `WORK_HISTORY.md`
- **Verification:** Workflow review

### DOC-003 — Decision traceability

- **Priority:** MUST
- **Status:** Accepted
- **Requirement:** Material architecture or requirement changes shall include a brief rationale in the documentation or Git commit history.
- **Verification:** Document and Git review

### DOC-004 — No silent requirement changes

- **Priority:** MUST
- **Status:** Accepted
- **Requirement:** AI tools shall not silently modify accepted requirements to fit a proposed design.
- **Verification:** Review

### DOC-005 — Assumptions

- **Priority:** MUST
- **Status:** Accepted
- **Requirement:** Unverified assumptions shall be labeled as assumptions, provisional values, or TBD items.
- **Verification:** Document review

### DOC-006 — Measurement references

- **Priority:** MUST
- **Status:** TBD
- **Requirement:** Decisions based on measurements shall reference the relevant raw data file, plot, or work-history entry.
- **Verification:** Document review

### DOC-007 — CAD revision linkage

- **Priority:** SHOULD
- **Status:** TBD
- **Requirement:** Major CAD revisions should be linked to a Git commit, tag, or documented model version.
- **Verification:** Git and document review

### DOC-008 — Superseded concepts

- **Priority:** SHOULD
- **Status:** Accepted
- **Requirement:** Rejected or superseded concepts should remain recoverable through Git or be briefly recorded with the reason they were abandoned.
- **Verification:** Git and document review

### DOC-009 — Units

- **Priority:** MUST
- **Status:** Accepted
- **Requirement:** Engineering values shall state units. CAD dimensions should use millimeters as the primary unit, with inches included when useful.
- **Verification:** Document review

### DOC-010 — Current next action

- **Priority:** MUST
- **Status:** Accepted
- **Requirement:** `WORK_HISTORY.md` shall identify one clear immediate next goal rather than an unprioritized collection of possible tasks.
- **Verification:** Document review

---

## 16. Future Indoor Active-Speaker Compatibility

These requirements are deferred for V1 and shall not override vehicle fit or first-prototype simplicity.

### FUT-001 — Indoor mono mode

- **Priority:** DEFERRED
- **Status:** Accepted
- **Requirement:** A future revision may operate as an indoor mono loudspeaker.

### FUT-002 — Internal amplification

- **Priority:** DEFERRED
- **Status:** Accepted
- **Requirement:** A future revision may contain an internal multi-channel amplifier and DSP.

### FUT-003 — Passive external-amplifier mode

- **Priority:** DEFERRED
- **Status:** Provisional
- **Requirement:** A future indoor revision should retain a practical way to operate from an external amplifier if this does not create unsafe switching or unnecessary complexity.

### FUT-004 — Safe mode selection

- **Priority:** DEFERRED
- **Status:** Accepted
- **Requirement:** Any future active/passive mode selection shall prevent an internal amplifier output from being electrically connected to an external amplifier output.

### FUT-005 — Future expansion space

- **Priority:** MAY
- **Status:** Provisional
- **Requirement:** V1 may preserve space or mounting provisions for future electronics only when doing so does not materially reduce required acoustic volume or delay the prototype.

---

## 17. Open Requirement Values

The following values or decisions must be resolved later:

1. Exact verified vehicle installation envelope
2. Required front-seat movement range
3. Required usability of the center rear seating position
4. Positive restraint method
5. Retention load target
6. Final assembled mass
7. Final print material
8. Material temperature-validation target
9. Net woofer chamber volume
10. Net midrange chamber volume
11. Woofer sealed-box alignment target
12. Midrange damping strategy
13. Tweeter model
14. Tweeter mounting position and orientation
15. Grille structure and required load resistance
16. Amplifier minimum safe impedance and reactive-load limits
17. Internal wire gauge and connector ratings
18. Woofer-to-midrange DSP crossover
19. Midrange/tweeter crossover topology and component values
20. Reference SPL
21. Maximum safe SPL or DSP limiter threshold
22. Numerical final frequency-response target
23. Required low-frequency extension
24. Measurement procedure and microphone positions
25. Impedance-measurement hardware and workflow
26. Authoritative CAD source when CodeCAD and SolidWorks coexist

---

## 18. V1 Acceptance Gate

The first complete vehicle prototype shall not be considered ready for normal use until all of the following are true:

- [ ] Physical driver dimensions have been verified.
- [ ] The enclosure fits the vehicle without unacceptable interference.
- [ ] A positive mechanical restraint is installed.
- [ ] The enclosure has no visible structural print failure.
- [ ] Driver frames and chamber penetrations are sealed.
- [ ] Drivers are protected from passenger contact.
- [ ] Both amplifier input pairs are electrically isolated.
- [ ] Continuity and polarity are verified.
- [ ] The woofer path has a known DSP low-pass.
- [ ] The midrange/tweeter path has a known DSP high-pass.
- [ ] The tweeter has passive low-frequency protection.
- [ ] Low-level individual-driver sweeps have been completed.
- [ ] The completed passive network impedance has been checked.
- [ ] The crossover has been validated at low and moderate output.
- [ ] No audible enclosure, grille, wiring, or vehicle-contact rattle is present.
- [ ] A conservative normal-use DSP preset has been saved.
- [ ] The installed configuration and wiring are recorded in `WORK_HISTORY.md`.

---

## 19. AI Maintenance Instructions

When maintaining this file:

1. Do not convert provisional values into accepted requirements without evidence or user approval.
2. Do not record completed work here unless it changes a requirement or verifies one.
3. Put chronological activity, results, failures, and next steps in `WORK_HISTORY.md`.
4. Keep requirement IDs stable.
5. Add new requirements in the most relevant section.
6. Mark replaced requirements as superseded rather than deleting their history without explanation.
7. Prefer measurable language such as “shall not contact,” “shall remain sealed,” or “shall be measured” over subjective language such as “should be good.”
8. When a subjective criterion is unavoidable, define how it will be evaluated.
9. Treat safety-related requirements as blocking items.
10. Treat the current CAD dimensions as a prototype baseline until vehicle fit and acoustic modeling validate them.

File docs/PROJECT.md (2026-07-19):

# Tesla Rear-Cabin Speaker Project

## Project Summary

This project is the design, fabrication, installation, and tuning of a custom high-fidelity loudspeaker system for the rear cabin of a Tesla Model 3.

The initial speaker will be a single, compact enclosure positioned on the rear floor behind the center console. The enclosure must use the limited available space efficiently, remain stable in the vehicle, avoid permanent modification of the car, and integrate with the vehicle's existing programmable DSP amplifier.

The first major goal is a fully functional and acoustically tuned prototype powered by two independent 65 W / 4 ohm amplifier outputs. The longer-term goal is to develop the enclosure and electronics into a more polished system that can also be adapted for use as a self-contained indoor mono loudspeaker.

This document is the high-level source of truth for the project. It defines the project vision, overall architecture, design philosophy, methods, broad current state, and major phases of work. Detailed constraints will be maintained separately in `REQUIREMENTS.md`, while completed work, test results, and immediate next actions will be maintained in `WORK_HISTORY.md`.

---

## Primary Goals

1. Design and build a high-fidelity rear-cabin speaker that fits behind the center console of the Tesla Model 3.
2. Use the available vehicle space as efficiently as possible while preserving passenger comfort, seat movement, HVAC airflow, and serviceability.
3. Integrate the speaker with two independently configurable 65 W / 4 ohm amplifier outputs.
4. Use DSP for routing, input mixing, EQ, delay, dynamics, and the woofer-to-midrange crossover.
5. Use a passive crossover between the midrange and tweeter for the first complete prototype.
6. Build the enclosure primarily through parametric CAD and large-format 3D printing.
7. Measure and tune the final acoustic system in the actual enclosure and installation environment.
8. Maintain a durable project record that can be read and updated by both the user and AI tools.
9. Preserve a path toward a future active, self-powered indoor mono speaker version.

---

## Current System Concept

The current design is a three-driver mono loudspeaker:

- One 8-inch woofer
- One 4.5-inch dedicated midrange
- One tweeter

The currently selected main drivers are:

- **Woofer:** Scan-Speak Revelator 22W/4851T00, 4 ohm (purchased)
- **Midrange:** Scan-Speak Illuminator 12MU/4731T00, 4 ohm (purchased)
- **Tweeter:** Current working selection: Scan-Speak Illuminator D3004/662000, 4 ohm (physical verification pending)

The vehicle amplifier provides two independent powered outputs. Each output can be assigned an arbitrary input mix and can be independently configured with filters, EQ, time alignment, level, panning, and dynamics processing.

The intended first complete architecture is:

```text
DSP amplifier output 1
    -> active low-pass and tuning in amplifier software
    -> woofer

DSP amplifier output 2
    -> active high-pass and tuning in amplifier software
    -> passive midrange/tweeter crossover
        -> midrange
        -> tweeter
```

Both amplifier outputs will receive the same intended mono program mix unless testing indicates that a different routing strategy produces better results.

This hybrid architecture keeps the low-frequency crossover in DSP, where it is easy to tune and does not require large passive components, while allowing the midrange and tweeter to share the second amplifier output through a passive crossover.

---

## Enclosure Concept

The enclosure is designed to sit on the rear floor behind the center console.

**Important note on current baseline:** The CodeCAD model currently represents a two-driver mechanical baseline (woofer + midrange). The intended V1 system adds a third driver (tweeter) with a passive midrange/tweeter crossover. Documentation and CAD updates to fully integrate the tweeter are in progress.

The current prototype concept is:

- Primarily one-piece large-format 3D-printed structural shell
- Removable, gasketed side-access panels for service and future expansion
- **Nominal body dimensions:** 241.3 mm (width) × 410 mm (length) × 220 mm (height)
- **Generated STL envelope (preliminary):** 246.3 mm × 415 mm × 253.05 mm (height variation due to baffle and feet)
- Sealed woofer chamber
- Separate sealed midrange chamber
- Internal divider between woofer and midrange volumes
- Internal bracing to reduce panel vibration
- Raised driver baffles
- Isolation feet with Sorbothane contact pads
- Wire pass-throughs for each chamber
- Parametric geometry so dimensions can be adjusted without rebuilding the model from scratch

The enclosure is currently being generated primarily with CodeCAD in Lua. More detailed geometry, fit refinement, mounting features, and cosmetic work may be completed in SolidWorks.

The design should remain easy to revise. Prototype print time and material use are acceptable costs if a new enclosure revision materially improves fit, strength, serviceability, or acoustic performance.

**Current immediate milestone:** Establish fabrication readiness by inventorying the delivered hardware, commissioning the 3D printer, and completing one documented calibration print. Physical driver and vehicle-envelope verification follow before the removable-panel CAD revision and full-size printing.

---

## Design Philosophy

### Prototype First

The first version is intended to prove that the concept works mechanically, electrically, and acoustically. It does not need to be the final polished product.

The prototype should answer questions such as:

- Does the enclosure fit the vehicle correctly?
- Is the enclosure stable during normal driving?
- Are the chamber volumes usable for the selected drivers?
- Does the cabinet rattle, resonate, flex, or leak?
- Can the system achieve useful output from the available amplifier power?
- Can the woofer, midrange, and tweeter be integrated successfully?
- Is the rear-floor location acoustically effective?
- What enclosure or crossover changes are required for the next revision?

### Measure Before Finalizing

Datasheets, simulations, and textbook crossover calculations are useful starting points, but the final design must be based on measurements of the actual drivers in the actual enclosure.

The project will use acoustic measurements to guide:

- Crossover design
- Driver level matching
- Polarity
- Delay and time alignment
- Equalization
- Resonance control
- Enclosure revision
- Final system validation

Each driver should be measured independently before the final crossover is selected. The completed system should then be measured again after integration.

### Use DSP Where It Provides the Most Value

The Tesla amplifier already provides extensive signal-processing capability. DSP should be used for operations that are difficult, expensive, or inflexible to perform passively, including:

- Input mixing
- Mono summing
- Woofer-to-midrange crossover
- Equalization
- Delay and time alignment
- Level control
- Dynamics and limiting
- Installation-specific tuning

Passive components should be used only where they are necessary or where they simplify the system.

### Preserve Modularity

Where practical, the design should allow major subsystems to be revised independently:

- Enclosure
- Drivers
- Passive crossover
- Wiring
- Terminal panel
- DSP configuration
- Future internal amplification

The enclosure should not unnecessarily lock the project into a single crossover, amplifier, or final use case.

### Document Decisions

Important design decisions should be recorded with their reasoning. AI tools should not infer that an old idea is still current when a later decision supersedes it.

The documentation should distinguish among:

- Confirmed decisions
- Current working assumptions
- Open questions
- Experimental ideas
- Rejected approaches
- Measured results

---

## Engineering and Development Methods

The project will use an iterative engineering workflow:

```text
Define goal
    -> model
    -> fabricate
    -> assemble
    -> measure
    -> analyze
    -> revise
    -> validate
```

The main tools and methods include:

### CAD and Mechanical Design

- CodeCAD in Lua for parametric enclosure generation
- SolidWorks for detailed modeling and refinement
- Vehicle measurements and, if useful, local 3D scanning
- Test coupons and partial prints before full enclosure prints
- Parametric control of major dimensions and mounting geometry

### Fabrication

- Large-format FDM 3D printing
- Mechanically reinforced walls, ribs, and braces
- Threaded inserts or other serviceable fasteners where appropriate
- Gaskets and sealants for acoustic sealing
- Sorbothane or similar isolation material for floor contact

### Electrical Integration

- Two isolated amplifier output channels
- Direct powered connection to the woofer
- Passive crossover between the midrange and tweeter
- Binding posts or another serviceable enclosure interface
- Safe tweeter protection during early testing
- Reversible wiring wherever practical

### Acoustic Measurement

- Calibrated or otherwise suitable measurement microphone
- Pink noise, sweeps, and individual-driver measurements
- Near-field and listening-position measurements as appropriate
- Measurement software such as REW
- Crossover simulation software such as VituixCAD
- Low-volume validation before high-output testing

### Version Control and Documentation

- Git for source history and rollback
- Obsidian for human-readable project documentation
- Continue and other AI-enabled development tools for code, analysis, and documentation
- Markdown files as the primary durable knowledge format

---

## Documentation Structure

The initial documentation set will consist of three main files:

### `PROJECT.md`

This file. It contains the broad project overview, architecture, methods, goals, current state, and long-term direction.

### `REQUIREMENTS.md`

A detailed list of mechanical, electrical, acoustic, manufacturing, safety, installation, and usability constraints. Requirements should be testable wherever possible.

### `WORK_HISTORY.md`

A chronological engineering log containing:

- Work completed
- Changes made
- Tests performed
- Results
- Problems found
- Decisions made
- Current blockers
- Immediate next goal

Additional files may be added later for specific topics such as measurements, crossover design, bill of materials, DSP settings, assembly procedures, risks, and enclosure revisions.

---

## Current Project State

The project is currently in the fabrication-readiness and physical-verification stage. The printer, speakers, filament, tools, and related supplies have been reported as delivered, but exact inventory and physical verification are pending.

Completed or substantially developed work includes:

- Selection and purchase of the woofer and midrange
- Selection of the rear-floor location behind the center console
- Selection of the broad two-channel hybrid active/passive architecture
- Selection of a current working tweeter (D3004/662000, pending physical verification)
- Parametric CAD development of the first enclosure prototype (currently a two-driver mechanical baseline)
- Definition of separate sealed woofer and midrange chambers
- Addition of basic bracing, feet, isolation-pad recesses, driver openings, and wire pass-throughs
- Establishment of Git and AI-assisted development workflows
- Initial investigation of crossover strategies and measurement workflow
- Preliminary chamber volume calculations (woofer: ~12.04 L, midrange: ~5.70 L)

Items still in development include:

- Removable, gasketed side-access panel design and validation
- Final tweeter physical verification and baffle integration
- Verification of exact driver mounting dimensions
- Detailed chamber-volume analysis (midrange chamber in particular)
- Final enclosure fit verification in vehicle
- Electrical terminal and internal wiring design
- Prototype fabrication
- Driver-by-driver acoustic measurement
- Passive midrange/tweeter crossover design
- Final DSP tuning
- Installation and road testing

The current CAD model should be treated as a first prototype rather than a frozen design. Enclosure geometry remains parametric and revision-ready.

---

## Major Project Phases

### Phase 1: Project Definition

Establish the project documents, architecture, requirements, selected components, open questions, and near-term milestones.

### Phase 2: Prototype Enclosure Design

Complete the first printable enclosure, verify driver fit, confirm vehicle packaging, and prepare the model for fabrication.

### Phase 3: Mechanical Prototype

Print and assemble the enclosure, install the drivers and hardware, inspect sealing and rigidity, and verify fit in the vehicle.

### Phase 4: Basic Electrical Operation

Wire the woofer and midrange/tweeter paths safely, confirm that each driver produces sound, and establish conservative DSP settings for testing.

### Phase 5: Individual Driver Measurement

Measure the woofer, midrange, and tweeter independently in the completed enclosure. Record response, phase, level, and any obvious cabinet problems.

### Phase 6: Passive Crossover Development

Use measured data to design and build the midrange/tweeter passive crossover. Measure, revise, and validate the crossover in the actual enclosure.

### Phase 7: Full-System DSP Tuning

Tune the woofer-to-midrange transition, EQ, delay, level, and dynamics using the Tesla amplifier software.

### Phase 8: Vehicle Validation

Evaluate the installed speaker for sound quality, rattles, stability, thermal behavior, passenger interference, and performance under real driving conditions.

### Phase 9: Revision and Refinement

Use the first prototype's results to decide whether to modify the enclosure, crossover, driver placement, mounting, materials, or system architecture.

### Phase 10: Future Active/Home Version

Develop a later revision that can operate as an indoor mono speaker using an internal amplifier, DSP, power supply, and appropriate input interface.

---

## Definition of Success for the First Complete Prototype

The first complete prototype will be considered successful when:

- The enclosure fits behind the center console without unsafe or unacceptable interference.
- The enclosure remains stable and does not create significant rattles or vibration noise.
- All three drivers operate safely from the two amplifier channels.
- The woofer and midrange/tweeter paths can be tuned independently.
- The passive midrange/tweeter crossover provides safe and usable integration.
- The system produces a subjectively convincing improvement in rear-cabin sound.
- Measured response is sufficiently controlled to support further DSP tuning.
- The prototype produces clear lessons and measurable direction for the next revision.

The first prototype does not need to achieve final cosmetic quality, perfect frequency response, or a finished home-speaker conversion.

---

## Guidance for AI Assistants

When working on this project, AI tools should:

1. Read this file first.
2. Read `REQUIREMENTS.md` before recommending mechanical, electrical, or acoustic changes.
3. Read the most recent entries in `WORK_HISTORY.md` before proposing the next action.
4. Treat measured results as more authoritative than generic calculations or assumptions.
5. Clearly distinguish confirmed facts from estimates and hypotheses.
6. Avoid silently changing the established architecture.
7. Explain when a recommendation conflicts with an existing decision.
8. Prefer small, testable next steps over large speculative redesigns.
9. Update documentation when decisions, results, or project state materially change.
10. Preserve revision history rather than overwriting the reasoning behind prior decisions.

---

## Long-Term Vision

The long-term objective is not merely to place an additional speaker in the car. It is to create a carefully engineered, measurable, serviceable loudspeaker platform that uses the unusual flexibility of the Tesla DSP amplifier, makes effective use of a constrained installation space, and can evolve through documented prototype revisions.

A successful final system should combine:

- High-quality drivers
- A rigid custom enclosure
- Well-controlled passive and active filtering
- Measurement-based tuning
- Reversible vehicle installation
- Maintainable project documentation
- A practical path to future indoor active-speaker use

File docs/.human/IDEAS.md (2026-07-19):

# Ideas

## Design Ideas (concrete)

- Remove the side panels and make them screw-in for access to speaker and electronics
- Figure out what bolts/fasteners I will use for the speaker drivers
- Decide on bolts/assembly for the side panel. Threaded inserts maybe?
- Add gasket grooves anywhere there are faces being joined
- Adapt perfectly to car interior geometry so that the speaker is snug and looks (somewhat) OEM

## Design Ideas (speculative)

- Add Keystone binding posts
- Make this an adaptable speaker that can be unplugged from the car and used inside
- Maybe add one of those holes that subwoofers are supposed to have? I think you need to do some calculations to figure out the hole diameter and placement and such
- Add some sort of button, switch, or knobs that remotely connect to the AMP and adjust settings (like turning on bass boost or something)

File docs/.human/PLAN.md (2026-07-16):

# Design Plan and Next Steps

- Remove the side panels and make them screw-in for access to speaker and electronics
- Add Keystone binding posts
- Figure out what bolts/fasteners I will use for the speaker drivers
- Decide on bolts/assembly for the side panel. Threaded inserts maybe?
- Add gasket grooves anywhere there are faces being joined

## Future Design Ideas

- Add a tweeter and make this an adaptable speaker that can be unplugged from the car and used inside
- Adapt perfectly to car interior geometry so that the speaker is snug and looks (somewhat) OEM
- Maybe add one of those holes that subwoofers are supposed to have? I think you need to do some calculations to figure out the hole diameter and placement and such
- Add some sort of button, switch, or knobs that remotely connect to the AMP and adjust settings (like turning on bass boost or something)

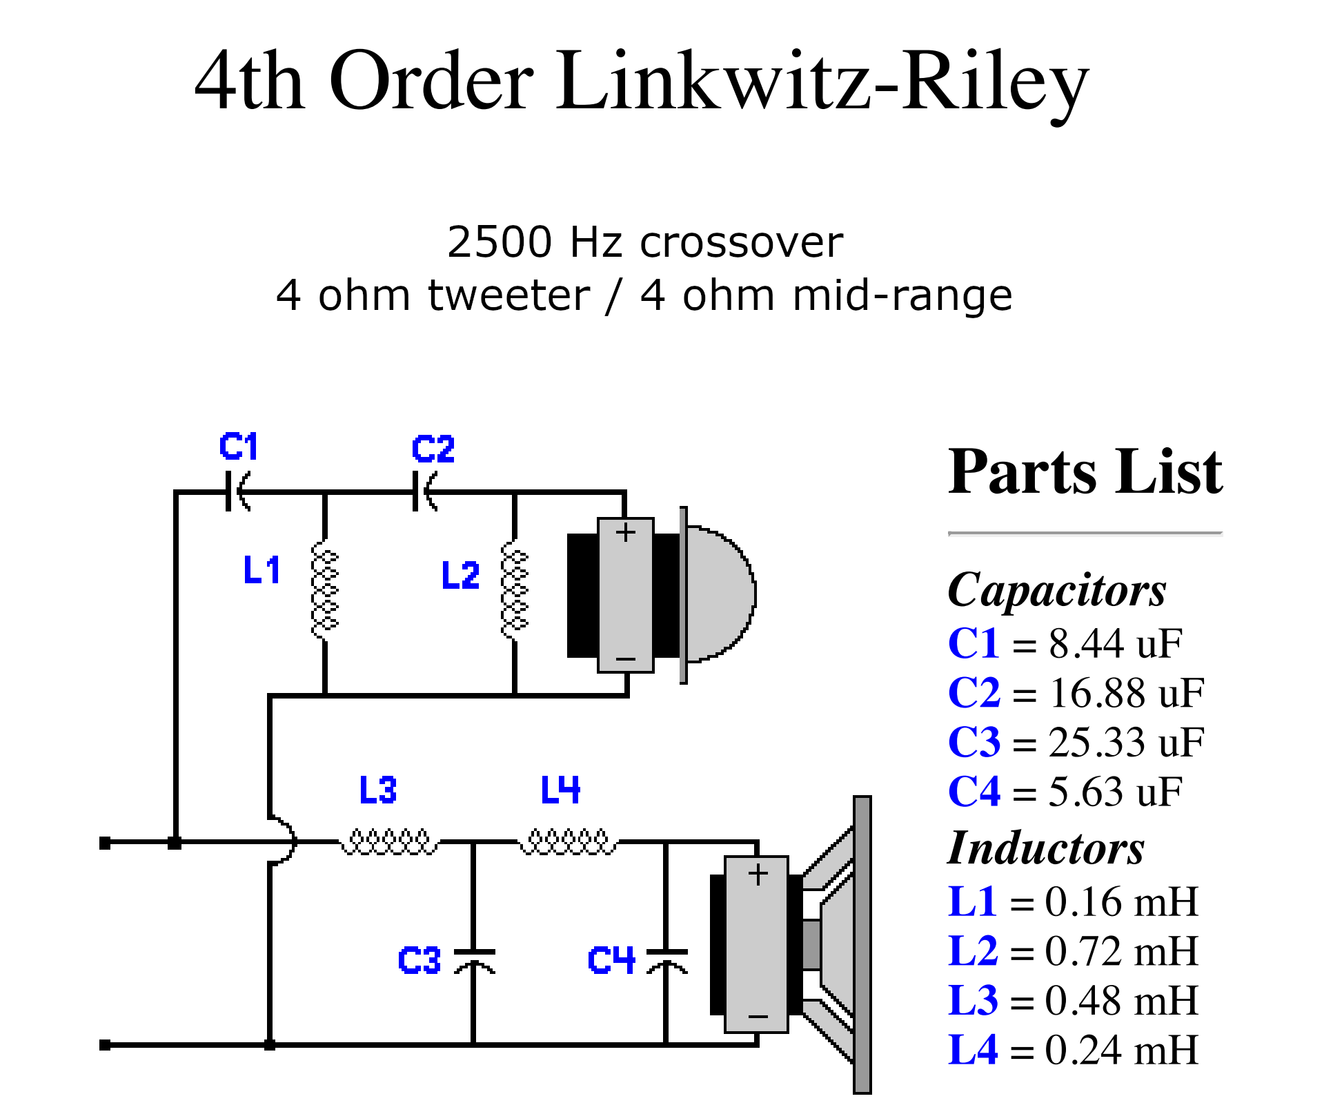
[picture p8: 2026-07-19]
assets/schematics/midrange_tweeter_crossover.png

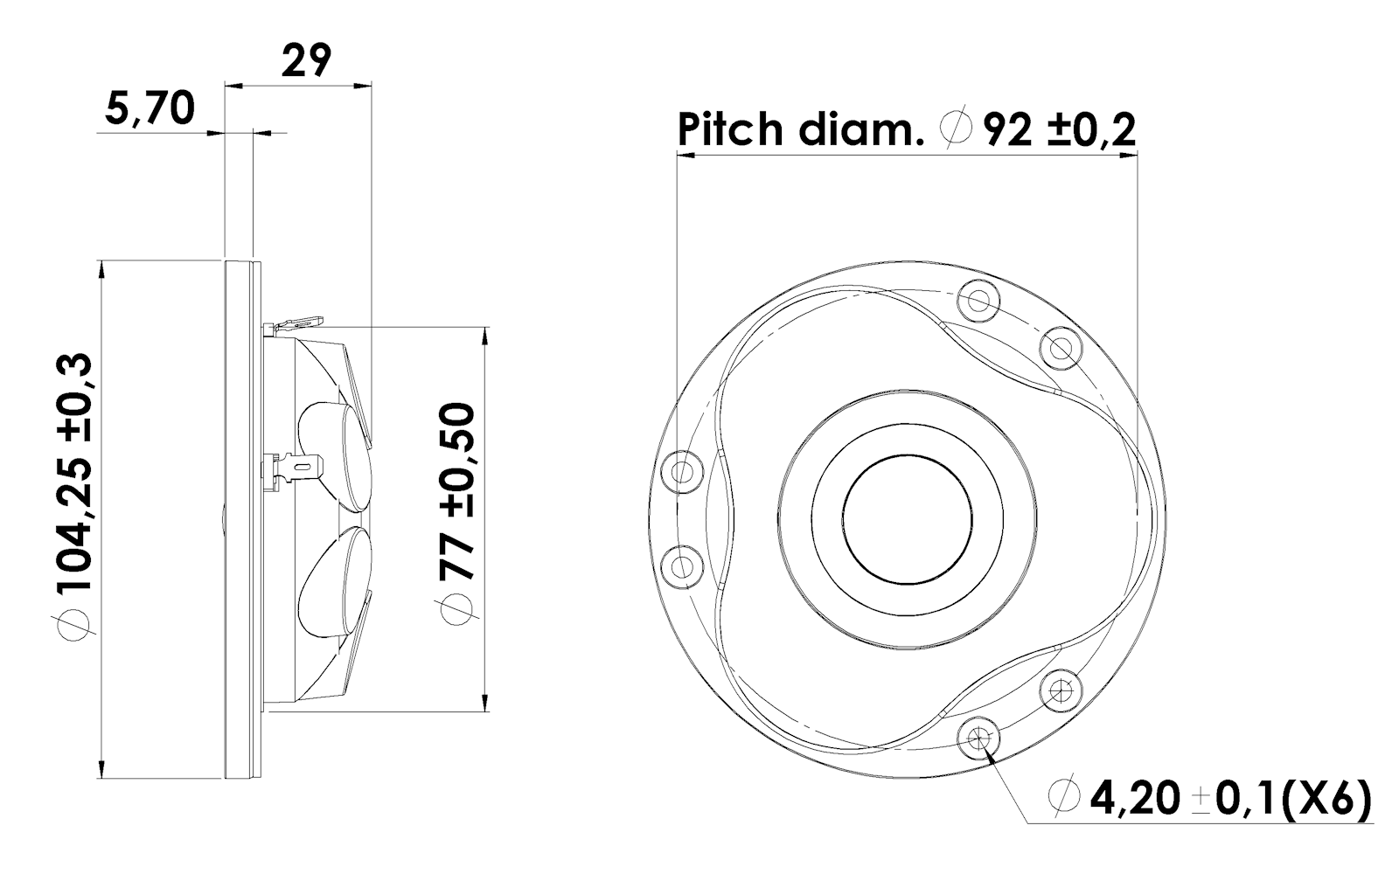
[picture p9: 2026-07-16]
assets/images/d3004-662000_DIMS.png

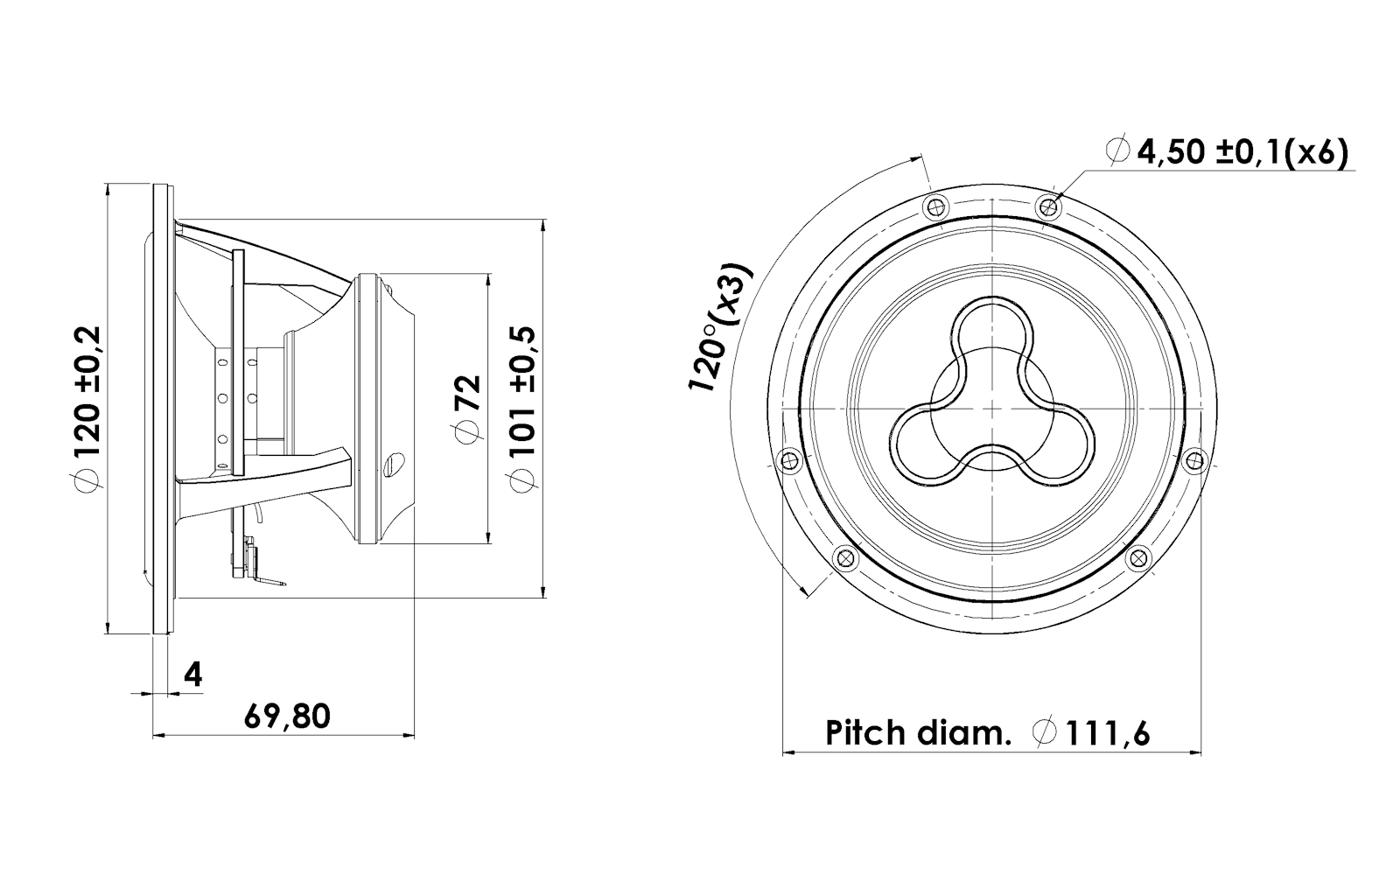
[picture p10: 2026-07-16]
assets/images/12MU-4731T00_DIMS.png

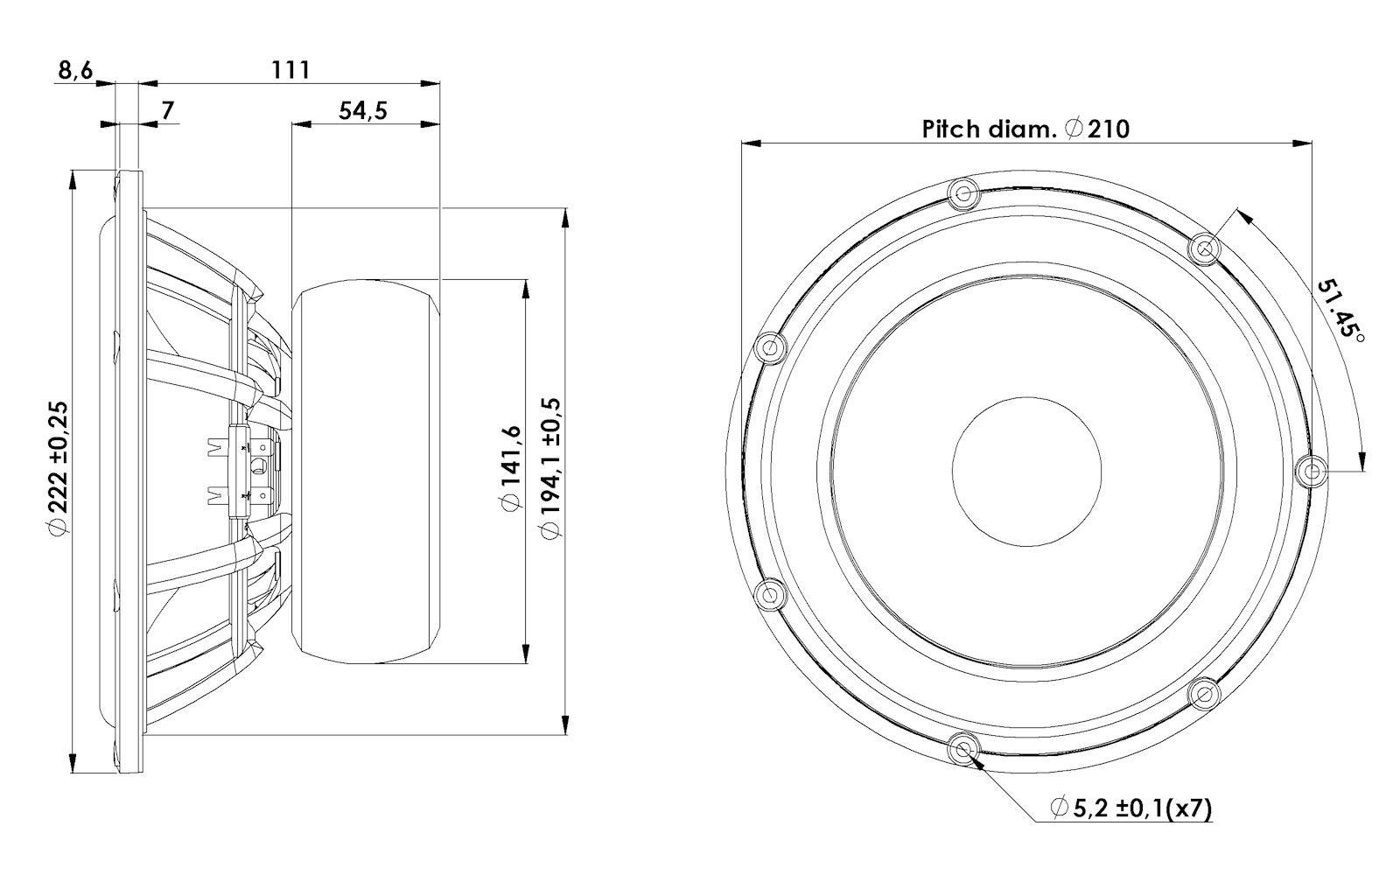
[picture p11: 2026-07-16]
assets/images/22W-4851T00_DIMS.png

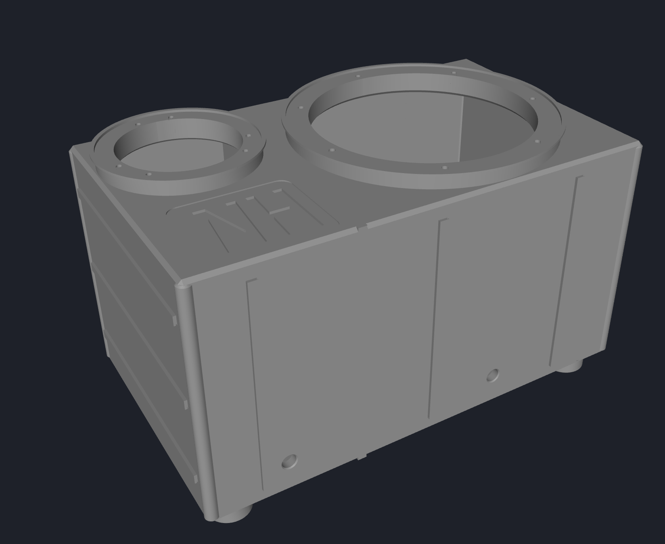
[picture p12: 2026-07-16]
assets/images/cabinet_render.png

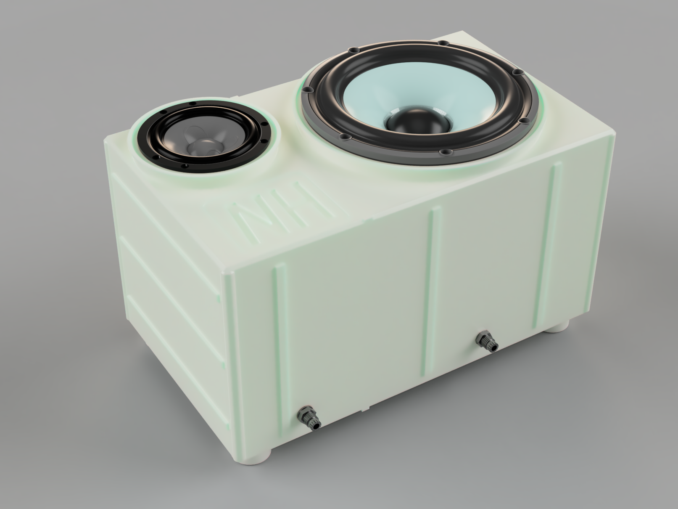
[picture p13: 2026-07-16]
assets/images/perspective_render_with_speakers_2.png

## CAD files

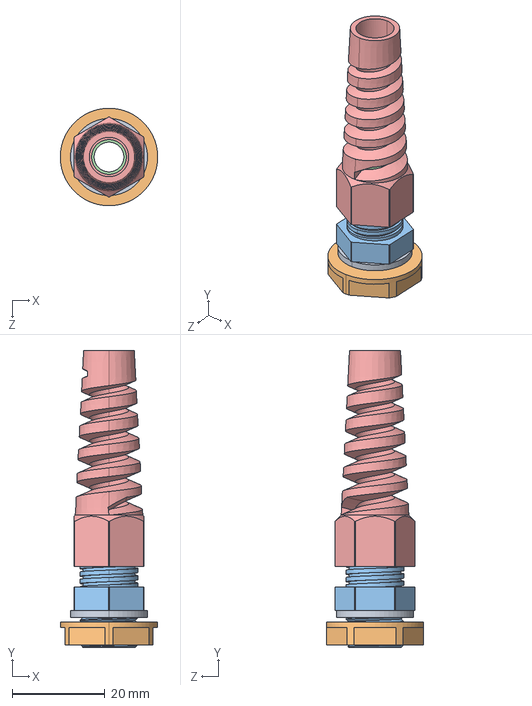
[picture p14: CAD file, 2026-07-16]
assets/objects/PG7_CABLE_GLAND.STEP
21.0 x 64.0 x 21.0 mm

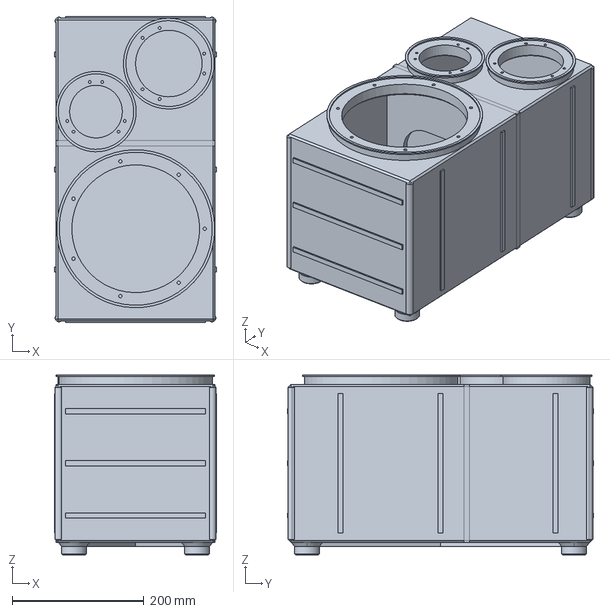
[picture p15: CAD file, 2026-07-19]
generated/part.step
246.3 x 465.0 x 273.1 mm

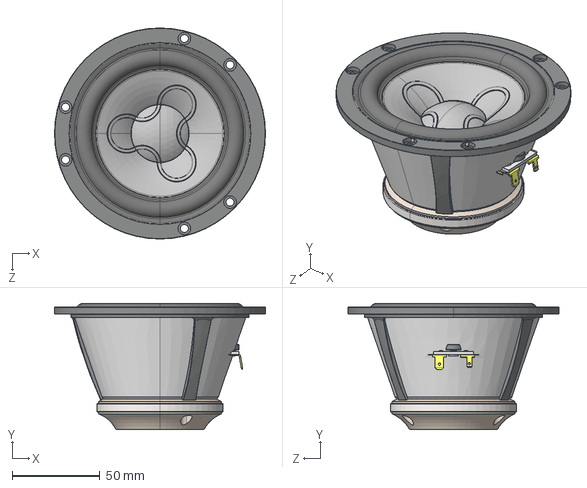
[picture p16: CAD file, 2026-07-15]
assets/objects/12MU-4731T00.STEP
120.1 x 71.9 x 120.1 mm

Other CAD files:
generated/part.stl

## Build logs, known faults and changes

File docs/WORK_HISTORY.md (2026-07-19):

---
document: WORK_HISTORY
project: Tesla Rear-Cabin Speaker
status: Active
version: 0.1
last_updated: 2026-07-18
current_phase: Fabrication readiness and physical verification
immediate_next_goal: Inventory the delivered equipment and commission the 3D printer with a documented calibration print
---

# Tesla Rear-Cabin Speaker — Work History

## 1. Purpose

This file is the chronological engineering record for the Tesla rear-cabin speaker project.

It documents:

- work completed
- decisions made
- artifacts created
- results observed
- assumptions used
- unresolved problems
- work that was considered but not implemented
- the current blocker or immediate next goal

This file is not a substitute for:

- `PROJECT.md`, which defines the high-level project purpose and architecture
- `REQUIREMENTS.md`, which defines the constraints the design must satisfy

The initial entries below reconstruct the project history from the current repository snapshot, supplied CAD and datasheet files, and the design discussion that preceded formal documentation. Exact dates are used only when they are known. Earlier work without a reliable date is grouped under a reconstructed baseline.

---

## 2. Maintenance Rules

When updating this file:

1. Add new work as a dated entry.
2. Record the result, not only the action.
3. Distinguish completed work from proposals and future ideas.
4. Include file paths, measurements, commits, or test data when available.
5. Record failures and rejected approaches; do not preserve only successful work.
6. State the next immediate goal as one small, actionable task.
7. Do not silently rewrite old results when later work changes the interpretation.
8. Add a correction or superseding entry instead.
9. Keep detailed requirements in `REQUIREMENTS.md`.
10. Keep broad project direction in `PROJECT.md`.

---

# 3. Current Snapshot

## Current phase

**Fabrication readiness and physical verification before the first full print**

The current repository contains a complete parametric two-driver enclosure model and generated STEP/STL exports. The mechanical model already includes two isolated sealed chambers, driver openings, internal bracing, isolation feet, cable-gland openings, and cosmetic exterior features.

The 3D printer, speakers, filament, tools, and additional project supplies have now been reported as delivered. Exact models, quantities, material types, and dimensions have not yet been inventoried or verified. The project can therefore move from planning-only work into physical validation, but it is not ready for a full enclosure print.

The project architecture has since expanded from a two-driver active prototype to a three-driver system using:

- one woofer channel
- one combined midrange/tweeter channel
- an active DSP crossover between the woofer and upper section
- a passive crossover between the midrange and tweeter

The current enclosure source has not yet been revised to include the tweeter, passive crossover access, binding posts, or removable service panels.

## Immediate next goal

**Inventory the delivered equipment and commission the 3D printer with a documented calibration print.**

The first work session should:

1. Record the printer model, nozzle size, build surface, and available slicer.
2. Record each filament type, diameter, and manufacturer; keep standard PLA limited to coupons and short-duration fit work.
3. Identify the physical woofer, midrange, and tweeter by exact model number and inspect for shipping damage.
4. Sort fasteners, inserts, gasket materials, terminals, wire, adhesives, and measurement tools by intended use.
5. Assemble and calibrate the printer according to its manufacturer procedure.
6. Print one small manufacturer-recommended calibration model and record material, profile, result, and any dimensional error.

This is the next task because every subsequent fit coupon and enclosure decision depends on knowing what hardware and material are actually available and whether the printer can produce dimensionally useful parts. After this gate passes, physically measure the drivers and vehicle envelope, then return to the removable-panel CAD revision and feature coupons.

## Current major blockers

- The physical woofer and midrange have not yet been used to verify all modeled mounting dimensions.
- The tweeter is not present in `parts/part.lua`.
- The exact tweeter position and orientation have not been selected.
- No removable service panel exists.
- Binding posts have not been integrated into the enclosure.
- Driver fasteners and insert geometry have not been finalized.
- Gasket grooves have not been added to removable joints.
- Chamber net volumes have not been formally calculated from the final design.
- No enclosure alignment simulation has been completed.
- No acoustic or impedance measurements have been recorded.
- No passive midrange/tweeter crossover has been designed from measurements.
- No positive vehicle crash restraint has been designed.
- The current generated enclosure has not yet been printed or test-fitted in the vehicle.

---

# 4. Current Design Baseline

## Source model

- **Primary parametric source:** `parts/part.lua`
- **CAD system:** CodeCAD
- **Language:** Lua
- **Project definition:** `project.json`
- **Units:** millimeters
- **Generated exports:** `generated/part.step` and `generated/part.stl`

The supplied `project.json` defines one visible part sourced from `parts/part.lua`, at unit scale with no transform.

## Nominal cabinet-body dimensions

The current source model defines:

| Parameter | Current value |
| --- | ---: |
| Outside width | 241.3 mm / 9.5 in |
| Cabinet length | 410 mm |
| Cabinet body height | 220 mm |
| Wall thickness | 8 mm |
| Divider start position  | Y = 270 mm |
| Divider thickness | 8 mm |
| Raised baffle thickness | 12 mm |
| Exterior edge chamfer | 3 mm |

These are body and feature parameters, not the complete installed envelope.

## Generated STL envelope

A mesh inspection of the supplied `part.stl` on 2026-07-18 produced:

| Result | Value |
| --- | ---: |
| Overall X extent |  246.3 mm |
| Overall Y extent |  415.0 mm |
| Overall Z extent | 253.05 mm |
| Connected mesh components | 1 |
| Topologically watertight after mesh processing | Yes |

The additional extent beyond the nominal cabinet body comes from features such as exterior ribs, corner bumpers, raised baffles, and feet.

This result confirms that the current generated mesh remains within the stated 420 × 420 × 480 mm printer build volume. Mesh watertightness does **not** prove that the physical print will be airtight.

## Preliminary gross chamber-volume calculation

A simple calculation from the current Lua parameters gives the following gross rectangular cavity volumes before subtracting braces, driver displacement, wire hardware, fillets, or other internal features:

| Chamber | Approximate gross volume |
| --- | ---: |
| Woofer chamber | 12.04 L |
| Midrange chamber | 5.70 L |
| Combined gross volume after divider | 17.74 L |

These are not final net acoustic volumes.

The manufacturer datasheets provide example sealed-box volumes of approximately:

- 16 L for the 22W/4851T00 woofer
- 0.9 L for the 12MU/4731T00 midrange

The current geometry therefore requires deliberate enclosure analysis rather than assuming that the modeled chamber division is acoustically final. The large midrange volume is especially likely to be revised or internally reduced.

---

# 5. Reconstructed Project History

## WH-001 — Initial goal established

- **Date:** Before formal documentation
- **Status:** Completed
- **Work:** Defined the general goal of improving the Tesla Model 3 rear-cabin sound with a custom high-quality speaker enclosure.
- **Result:** The project was framed as a custom, measurement-tuned loudspeaker rather than a simple off-the-shelf speaker installation.
- **Current relevance:** Still active.

## WH-002 — Rear-deck location investigated and rejected

- **Date:** Before formal documentation
- **Status:** Completed decision
- **Work:** Considered placing an approximately 8-inch speaker enclosure on the rear parcel shelf.
- **Result:** The rear-deck concept was rejected because an enclosure large enough to be useful would substantially obstruct rear-window visibility.
- **Decision:** Move the enclosure to the rear floor behind the center console.
- **Current relevance:** Superseded location concept; retained as design history.

## WH-003 — Rear-center floor location selected

- **Date:** Before formal documentation
- **Status:** Completed decision
- **Work:** Evaluated the rear floor behind the center console as the installation location.
- **Result:** The location was selected because it:
  - avoids blocking the rear window
  - provides more usable enclosure volume
  - supports the enclosure from the floor
  - permits reversible installation
  - can use a centered mono speaker architecture
- **Open issue:** Exact vehicle contour and positive restraint remain unresolved.

## WH-004 — Amplifier capabilities established

- **Date:** Before formal documentation
- **Status:** Completed
- **Work:** Confirmed that the vehicle amplifier provides two independent outputs, each nominally rated at 65 W into 4 ohms.
- **Result:** Each output can independently use:
  - arbitrary input routing and input mixing
  - left/right contribution control
  - crossover filters
  - EQ
  - delay and time alignment
  - gain and panning
  - dynamics processing
- **Design effect:** The two outputs do not need to represent fixed left and right channels.

## WH-005 — Two-channel system architecture selected

- **Date:** Before formal documentation
- **Status:** Completed decision
- **Work:** Compared multiple ways to power three drivers from two amplifier outputs.
- **Result:** Selected the following hybrid architecture:

```text
Amplifier output 1
    -> DSP low-pass
    -> woofer

Amplifier output 2
    -> DSP high-pass
    -> passive crossover
        -> midrange
        -> tweeter
```

- **Reason:** This keeps the low-frequency woofer/midrange transition in DSP and avoids large passive low-frequency crossover components.
- **Open issue:** Exact crossover frequencies and slopes remain measurement-dependent.

---

# 6. Driver Selection and Reference Data

## WH-006 — Woofer selected

- **Date:** Before formal documentation
- **Status:** Completed
- **Component:** Scan-Speak Revelator 22W/4851T00
- **Nominal impedance:** 4 ohms
- **Repository references:**
  - `22w-4851t00.pdf`
  - `22W-4851T00.STEP`
- **Important manufacturer data recorded:**
  - resonance frequency: 21 Hz
  - sensitivity: 89 dB at 2.83 V / 1 m
  - operating range: Fs–3000 Hz
  - linear excursion: ±9 mm
  - cabinet displacement: 1.04 L
  - example sealed volume: 16 L
  - example vented volume: 22 L
  - mounting cutout shown near 194 mm
  - seven-hole mounting pattern on a 210 mm pitch diameter
- **Result:** Woofer dimensions and bolt geometry were incorporated into the parametric enclosure.
- **Open issue:** Verify the physical driver before the full print.

## WH-007 — Midrange selected

- **Date:** Before formal documentation
- **Status:** Completed
- **Component:** Scan-Speak Illuminator 12MU/4731T00
- **Nominal impedance:** 4 ohms
- **Repository references:**
  - `12mu-4731t00.pdf`
  - `12MU-4731T00.STEP`
- **Important manufacturer data recorded:**
  - resonance frequency: 64 Hz
  - sensitivity: 90 dB at 2.83 V / 1 m
  - operating range: 100–10000 Hz
  - linear excursion: ±3.5 mm
  - cabinet displacement: 0.14 L
  - example sealed volume: 0.9 L
  - example vented volume: 1.5 L
  - frame diameter shown near 120 mm
  - mounting cutout shown near 101 mm
- **Result:** Midrange dimensions and bolt geometry were incorporated into the parametric enclosure.
- **Open issue:** Verify the physical driver before the full print.

## WH-008 — Tweeter candidate selected and reference assets added

- **Date:** Before 2026-07-18
- **Status:** Selected for current design development; purchase status not recorded
- **Component:** Scan-Speak Illuminator D3004/662000
- **Nominal impedance:** 4 ohms
- **Repository references:**
  - `d3004-662000.pdf`
  - `D3004_662000.STEP`
- **Important manufacturer data recorded:**
  - resonance frequency: 500 Hz
  - sensitivity: 91.5 dB at 2.83 V / 1 m
  - operating range: 2500–30000 Hz
  - faceplate diameter: approximately 104 mm
  - mounting pitch diameter: approximately 92 mm
  - six 4.2 mm mounting holes
  - manufacturer example crossover guidance: second-order high-pass Butterworth at 2.5 kHz
- **Result:** A matching-quality tweeter with supplied CAD geometry is available for packaging and crossover work.
- **Open issue:** The tweeter has not yet been added to the enclosure model, and its final location has not been selected.

## WH-009 — Driver CAD models collected

- **Date:** Before 2026-07-18
- **Status:** Completed
- **Work:** Added manufacturer STEP models for all three intended drivers.
- **Artifacts:**
  - `12MU-4731T00.STEP`
  - `22W-4851T00.STEP`
  - `D3004_662000.STEP`
- **Result:** Accurate reference solids are available for interference checks, baffle design, driver depth checks, and assembly renders.
- **Caution:** The Lua model currently uses manually encoded dimensions and does not directly consume the STEP solids.

---

# 7. CodeCAD Project and Parametric Modeling

## WH-010 — CodeCAD project initialized

- **Date:** Before 2026-07-15
- **Status:** Completed
- **Work:** Created a CodeCAD project using millimeters and a single Lua part source.
- **Artifacts:**
  - `project.json`
  - `parts/part.lua`
- **Result:** The enclosure can be regenerated and exported through the CodeCAD command-line workflow.
- **Current commands documented:**
  - `ccad live`
  - `ccad build`
  - `ccad doctor`
- **Housekeeping issue:** `project.json` still uses the generic project name `My CodeCAD Project`.

## WH-011 — Main cabinet envelope parameterized

- **Date:** Before 2026-07-15
- **Status:** Completed
- **Work:** Created parameters for:
  - width
  - length
  - wall thickness
  - height
  - divider position and thickness
- **Result:** The cabinet envelope can be adjusted without rewriting the construction logic.
- **Design constraint:** The 410 mm length was selected to keep the one-piece model within the stated printer build volume.

## WH-012 — Hollow sealed cabinet shell created

- **Date:** Before 2026-07-15
- **Status:** Completed
- **Work:** Constructed a chamfered outer body and subtracted an internal cavity.
- **Result:** The current model is a one-piece hollow enclosure with nominal 8 mm walls and a 3 mm exterior chamfer.
- **Limitation:** There is no removable access panel.

## WH-013 — Two sealed chambers created

- **Date:** Before 2026-07-15
- **Status:** Completed
- **Work:** Added a full-depth divider to isolate the woofer and midrange.
- **Result:** Woofer back pressure is prevented from directly modulating the midrange cone.
- **Current divider:** Starts at Y = 270 mm with 8 mm thickness.
- **Open issue:** The resulting chamber volumes have not been acoustically validated.

## WH-014 — Woofer mounting geometry added

- **Date:** Before 2026-07-15
- **Status:** Completed
- **Work:** Added:
  - 194.1 mm cutout
  - 222 mm frame allowance
  - seven-hole pattern
  - 105 mm bolt radius
  - 5.2 mm mounting holes
  - raised baffle
  - rear cutout flare
  - position parameters
- **Result:** The woofer opening and mounting pattern move together when the driver position changes.
- **Open issue:** Bolt type and threaded interface are undecided.

## WH-015 — Midrange mounting geometry added

- **Date:** Before 2026-07-15
- **Status:** Completed
- **Work:** Added:
  - 101 mm cutout
  - 120 mm frame allowance
  - six-hole pattern
  - approximately 55.8 mm bolt radius
  - 4.5 mm mounting holes
  - raised baffle
  - rear cutout flare
  - position parameters
- **Result:** The midrange opening and mounting pattern move together when the driver position changes.
- **Open issue:** Bolt type and threaded interface are undecided.

## WH-016 — Raised baffles and trim rings added

- **Date:** Before 2026-07-15
- **Status:** Completed
- **Work:** Added 12 mm raised circular baffles and shallow cosmetic trim rings around both driver positions.
- **Result:** Driver mounting surfaces are locally thickened, and the enclosure has a more finished appearance.
- **Open issue:** The acoustic effect of the raised baffles and nearby geometry has not been measured.

## WH-017 — Rear cutout flares added

- **Date:** Before 2026-07-15
- **Status:** Completed
- **Work:** Added conservative rear-side cutout relief behind both cone drivers.
- **Result:** Rear cone airflow is less restricted while mounting-hole material is preserved.
- **Open issue:** Verify clearance with physical driver baskets and terminals.

## WH-018 — Woofer window brace added

- **Date:** Before 2026-07-15
- **Status:** Completed
- **Work:** Added a full-height internal brace near Y = 245 mm with a rounded pill-shaped opening.
- **Result:** The brace couples the long cabinet panels while preserving an acoustically continuous woofer chamber.
- **Open issue:** The brace displacement has not yet been subtracted from the woofer net volume.

## WH-019 — Wire pass-throughs added

- **Date:** Before 2026-07-15
- **Status:** Completed
- **Work:** Added one 12.5 mm side-wall pass-through for each sealed chamber.
- **Result:** Each chamber has a planned cable entry sized for a PG7 cable gland.
- **Open issue:** The final external wiring and terminal arrangement may change now that binding posts and a passive crossover are planned.

## WH-020 — PG7 cable-gland reference model added

- **Date:** Before 2026-07-18
- **Status:** Completed
- **Artifact:** `PG7_CABLE_GLAND.STEP`
- **Result:** Cable-gland packaging can be checked in assembly CAD.
- **Repository result:** The README records an assembly render with both drivers and PG7 cable glands installed.
- **Open issue:** The cable gland has not been integrated as a parametric solid in `parts/part.lua`.

---

# 8. Structural, Isolation, and Cosmetic Development

## WH-021 — Isolation feet modeled

- **Date:** Before 2026-07-15
- **Status:** Completed
- **Work:** Added four cylindrical feet with:
  - 38.1 mm diameter
  - 19.05 mm projection below the cabinet body
  - flared collars
  - Sorbothane recesses
- **Result:** The enclosure has a defined interface for vibration-isolation pads.

## WH-022 — Sorbothane pad pockets modeled

- **Date:** Before 2026-07-15
- **Status:** Completed
- **Work:** Added recesses for 1.0625 inch diameter × 0.25 inch thick Sorbothane discs.
- **Result:** Pads can sit flush with the foot contact surfaces.
- **Open issue:** Final enclosure mass and pad compression must be known before confirming durometer and load suitability.

## WH-023 — Bottom X bracing added

- **Date:** Before 2026-07-15
- **Status:** Completed
- **Work:** Added two low-profile diagonal beams connecting the foot regions under the broad bottom panel.
- **Result:** The design intends to stiffen the bottom without extending below the isolation contact plane.
- **Open issue:** Confirm the braces do not create fit or printing problems.

## WH-024 — Exterior side and end ribs added

- **Date:** Before 2026-07-15
- **Status:** Completed
- **Work:** Added low-relief ribs to the long side walls and both end panels.
- **Result:** The enclosure gains visual structure and some additional panel stiffness.
- **Open issue:** Side ribs will need redesign if side walls become removable panels.

## WH-025 — Corner bumpers added

- **Date:** Before 2026-07-15
- **Status:** Completed
- **Work:** Added rounded vertical rails at the four enclosure corners.
- **Result:** Corners are visually tied to the exterior ribs and receive limited impact protection.

## WH-026 — Recessed badge and monogram added

- **Date:** Before 2026-07-15
- **Status:** Completed
- **Work:** Added a shallow rounded badge panel and engraved `NH` monogram.
- **Result:** The prototype has a custom visual identity.
- **Priority note:** Cosmetic features may be simplified if they interfere with service access, print reliability, fit, or acoustic requirements.

---

# 9. Generated Artifacts and Repository Documentation

## WH-027 — STEP and STL exports generated

- **Date:** 2026-07-15, based on the generated STEP metadata
- **Status:** Completed
- **Artifacts in repository:**
  - `generated/part.step` (solid exchange model)
  - `generated/part.stl` (printable mesh)
- **Result:** The CodeCAD model successfully generated both a solid exchange model and a printable mesh.
- **Note:** Dimensions are derived from the CodeCAD parametric output and require verification in the slicer and on the physical printer before committing to the full enclosure print.

## WH-028 — Assembly and cabinet renders created

- **Date:** Before 2026-07-18
- **Status:** Completed
- **Artifacts in repository:**
  - `assets/images/cabinet_render.png` (single cabinet view)
  - `assets/images/perspective_render_with_speakers.png` (two-driver assembly)
  - `assets/images/perspective_render_with_speakers_2.png` (alternative perspective)
- **Result:** The repository contains visual references for the cabinet and a two-driver assembly with cable glands.
- **Note:** The renders show the two-driver mechanical baseline; they do not yet include the tweeter or passive midrange/tweeter crossover configuration. README.md description remains as originally written and should be updated to reflect the final V1 system architecture.

## WH-029 — Repository README written

- **Date:** Before 2026-07-18
- **Status:** Completed
- **Artifact:** `README.md`
- **Result:** The repository now documents:
  - the enclosure purpose
  - selected woofer and midrange
  - current dimensions
  - current structural features
  - repository layout
  - CodeCAD build commands
  - parameter groups
  - initial printing and assembly guidance
- **Limitation:** The README still describes the enclosure as a two-driver prototype and does not reflect the selected tweeter or hybrid passive midrange/tweeter architecture.

## WH-030 — Initial design plan written

- **Date:** Before 2026-07-18
- **Status:** Completed
- **Artifact:** `PLAN.md`
- **Current near-term items recorded:**
  - make the side panels removable and screw-mounted
  - add Keystone binding posts
  - choose driver fasteners
  - choose side-panel fasteners and possible threaded inserts
  - add gasket grooves at joined faces
- **Future ideas recorded:**
  - add a tweeter and indoor adaptability
  - conform the enclosure more closely to the car interior
  - investigate a vented alignment
  - add physical remote controls for amplifier functions
- **Result:** The repository contains a concise pre-documentation task list.
- **Note:** Some “future” ideas, especially the tweeter, have since moved into the current system architecture.

## WH-031 — Formal project documentation started

- **Date:** 2026-07-18
- **Status:** Completed
- **Artifacts:**
  - `PROJECT.md`
  - `REQUIREMENTS.md`
  - `WORK_HISTORY.md`
- **Result:** The project now has separate documents for:
  - broad direction
  - detailed constraints
  - chronological engineering history
- **Next documentation task:** Audit `PROJECT.md` and `REQUIREMENTS.md` against the full repository context and correct any inconsistencies.

---

# 10. Hardware and Mechanical Integration Planning

## WH-032 — Keystone binding-post assembly selected as a reference

- **Date:** Before 2026-07-18
- **Status:** Reference component obtained; not integrated
- **Component:** Keystone Electronics 4109 dual binding-post assembly
- **Artifact:** `BINDING_POST_4109.STEP`
- **Result:** Accurate CAD geometry is available for an external speaker-level terminal interface.
- **Open issues:**
  - choose panel location
  - determine whether one or two dual assemblies are needed
  - add mounting geometry
  - provide internal wire clearance
  - seal the panel penetration
  - protect the posts from passenger contact

## WH-033 — Driver fastener decision identified

- **Date:** Before 2026-07-18
- **Status:** Open
- **Work:** Recognized that the driver mounting screws and printed-plastic interface must be selected before finalizing the baffles.
- **Candidate methods:**
  - heat-set threaded inserts
  - captive nuts
  - through-bolts where accessible
- **Result:** No fastener has been selected or tested.
- **Required next evidence:** Test-coupon pull-out and torque testing in the selected print material.

## WH-034 — Removable side-panel concept identified

- **Date:** Before 2026-07-18
- **Status:** Planned, not implemented
- **Work:** Proposed converting side walls into screw-mounted service panels.
- **Reason:**
  - access drivers and wiring
  - install and revise crossover components
  - install binding posts
  - inspect seals
  - support future electronics
- **Open issues:**
  - which side or sides should open
  - panel thickness
  - screw count and spacing
  - insert type
  - alignment lip
  - gasket geometry
  - effect on existing ribs and corner bumpers

## WH-035 — Gasketed joints identified as necessary

- **Date:** Before 2026-07-18
- **Status:** Planned, not implemented
- **Work:** Recognized that removable faces require gasket grooves or sealing lands.
- **Result:** No gasket profile or material has been selected.
- **Design requirement:** Removable panels must maintain chamber isolation and avoid buzzes under pressure and vehicle vibration.

---

# 11. Acoustic Architecture Development

## WH-036 — Sealed alignment selected for the first prototype

- **Date:** Before 2026-07-18
- **Status:** Completed decision
- **Work:** Chose a sealed two-chamber enclosure for the first prototype.
- **Result:** The current CAD has no port or passive radiator.
- **Reason:** Sealed construction is simpler to package, less sensitive to port geometry, and appropriate for a first measurement-driven prototype.
- **Future note:** A ported alignment was recorded as an idea but has not been analyzed or approved.

## WH-037 — Passive crossover theory investigated

- **Date:** Before 2026-07-18
- **Status:** Completed preliminary study
- **Work:** Investigated:
  - first-order filters
  - Butterworth filters
  - Linkwitz–Riley filters
  - capacitor and inductor behavior
  - nominal-impedance crossover calculators
- **Result:** Established that:
  - the tweeter requires passive low-frequency protection
  - the midrange requires upper-band attenuation
  - textbook networks based only on 4-ohm labels do not guarantee the intended acoustic response
  - final crossover values should come from measurements in the actual enclosure
- **No hardware result:** No crossover has been built.

## WH-038 — 2.5 kHz midrange/tweeter region selected as a starting point

- **Date:** Before 2026-07-18
- **Status:** Provisional
- **Work:** Evaluated 2.5 kHz as the initial midrange/tweeter crossover region.
- **Result:** The value is consistent with the D3004/662000 manufacturer's example guidance and the usable operating ranges of the selected drivers.
- **Caution:** This is not a final component calculation or guaranteed acoustic target.

## WH-039 — Measurement-first crossover workflow selected

- **Date:** Before 2026-07-18
- **Status:** Completed decision
- **Work:** Clarified that drivers can be measured one at a time and that a finished passive crossover is not required before individual driver measurements.
- **Result:** The intended workflow is:
  1. finish and assemble the enclosure
  2. connect and measure one driver at a time using safe filtering
  3. measure impedance
  4. design the passive network from measured data
  5. build and revise the network
  6. complete in-car DSP tuning
- **Tools already available:** A suitable acoustic measurement microphone is owned.
- **Tools/workflow still unresolved:** Impedance measurement hardware and exact measurement procedure.

---

# 12. Current Repository Asset Inventory

## Documentation and project configuration

- `README.md` — current two-driver repository overview
- `PLAN.md` — short next-step and future-idea list
- `project.json` — CodeCAD project definition
- `PROJECT.md` — high-level project document
- `REQUIREMENTS.md` — detailed project requirements
- `WORK_HISTORY.md` — this file

## Parametric and generated enclosure files

- `parts/part.lua` — current authoritative CodeCAD source
- `generated/part.step` — generated solid
- `generated/part.stl` — generated print mesh

## Driver datasheets

- `12mu-4731t00.pdf`
- `22w-4851t00.pdf`
- `d3004-662000.pdf`

## Driver and hardware CAD references

- `12MU-4731T00.STEP`
- `22W-4851T00.STEP`
- `D3004_662000.STEP`
- `BINDING_POST_4109.STEP`
- `PG7_CABLE_GLAND.STEP`

## Complete Repository Inventory

**CAD and manufacturing:**

- `parts/part.lua` — CodeCAD parametric enclosure generator (Lua)
- `generated/part.step` — Current solid exchange model (2026-07-15)
- `generated/part.stl` — Current printable mesh (2026-07-15)
- `generated/part.step` and `part.stl` are derived artifacts; regenerated by `parts/part.lua`

**Component reference models (in components/ or referenced by CAD):**

- `22W-4851T00.STEP` — Scan-Speak woofer (Revelator 8")
- `12MU-4731T00.STEP` — Scan-Speak midrange (Illuminator 4.5")
- `D3004_662000.STEP` — Scan-Speak tweeter (Illuminator dome, provisional)
- `BINDING_POST_4109.STEP` — Keystone binding-post assembly (provisional)
- `PG7_CABLE_GLAND.STEP` — Cable gland reference

**Renders and documentation:**

- `assets/images/cabinet_render.png` — Static cabinet visualization
- `assets/images/perspective_render_with_speakers.png` — Two-driver assembly render
- `assets/images/perspective_render_with_speakers_2.png` — Alternative perspective
- `README.md` — Repository overview (describes two-driver baseline; should be updated)
- `PLAN.md` — Early design planning notes

**Scripts:**

- `scripts/angle_calculator.js` — Utility for driver angle calculations (currently unused)

**Project documentation (also an Obsidian vault):**

- `docs/PROJECT.md` — High-level project vision and architecture
- `docs/REQUIREMENTS.md` — Detailed constraints and specifications
- `docs/WORK_HISTORY.md` — This file

**Git history:**

- Full commit history available via `git log`; recent commits documented in the entries above

---

# 13. Decisions Currently in Force

The following decisions should be treated as current unless explicitly superseded:

1. The enclosure is located behind the center console on the rear floor.
2. The enclosure is a centered mono loudspeaker.
3. The system uses one woofer, one midrange, and one tweeter.
4. The selected woofer is the Scan-Speak 22W/4851T00.
5. The selected midrange is the Scan-Speak 12MU/4731T00.
6. The working tweeter selection is the Scan-Speak D3004/662000.
7. The first system uses two independent 65 W / 4-ohm amplifier outputs.
8. The woofer uses one dedicated amplifier channel.
9. The midrange and tweeter share the second channel through a passive crossover.
10. The woofer/midrange transition is handled in DSP.
11. The first enclosure uses sealed chambers.
12. The first full print is a functional proof-of-concept rather than a permanent vehicle installation.
13. The enclosure remains parameterized and version-controlled.
14. Final crossover and DSP choices will be based on measurements.

---

# 14. Ideas Considered but Not Yet Approved

These concepts remain exploratory and shall not be treated as current requirements:

- ported or bass-reflex enclosure
- passive radiator
- exact OEM-shaped floor contour
- internal amplifier
- active/passive mode switch
- indoor self-powered mode
- remote physical DSP controls
- bass-boost button
- Bluetooth or network audio
- permanent vehicle mounting modification
- final cosmetic surface finish
- fully printed grille design
- stereo pair or dual-enclosure architecture

---

# 15. Near-Term Work Queue

Only the first item is the immediate goal. Later items may be reordered after each result.

## 1. Immediate — Removable side-access panel

- Select one side for the first access-panel implementation.
- Define the panel perimeter.
- Add a locating lip.
- Add gasket geometry.
- Add provisional insert bosses and screw holes.
- Remove or modify conflicting exterior ribs.
- Verify chamber separation.
- Create an insert/gasket test coupon.

## 2. Verify physical driver geometry

When the drivers arrive:

- measure frame diameter
- measure cutout requirement
- measure mounting-hole diameter
- verify bolt-circle locations
- measure rear depth
- inspect terminals and wire clearance
- compare all results against Lua parameters and STEP models

Do not commit to the full print until these checks are complete.

## 3. Add tweeter to the enclosure

- Import or reference the D3004 STEP model.
- evaluate available baffle positions
- minimize midrange/tweeter center spacing
- check passenger exposure
- check grille clearance
- verify internal chamber and fastener clearance
- add mounting and cutout geometry

## 4. Add binding-post interface

- Decide whether to use separate LF and MF/HF terminal pairs.
- place the Keystone 4109 reference model
- add mounting cutouts and fastener features
- preserve sealing
- protect rear wiring
- verify passenger clearance

## 5. Finalize driver and panel fasteners

- choose insert and screw sizes
- print test coupons
- test installation method
- test pull-out and strip torque
- record required pilot geometry

## 6. Calculate net chamber volumes

- calculate from final CAD
- subtract driver displacement
- subtract brace and hardware displacement
- compare with manufacturer guidance
- determine whether the midrange needs a much smaller internal sub-enclosure

## 7. Model the woofer sealed alignment

- use verified driver parameters
- simulate the actual net volume
- evaluate expected resonance, Q, excursion, and low-frequency response
- decide whether the current volume is acceptable for V1

## 8. Prepare print strategy

- select prototype material
- define nozzle and layer height
- define perimeter count
- define infill approach
- determine orientation and supports
- estimate material and print time
- decide whether a one-piece print remains practical

## 9. Print fit and hardware coupons

Before the complete cabinet:

- driver-hole coupon
- insert coupon
- access-panel gasket coupon
- binding-post panel coupon
- PG7 gland coupon
- Sorbothane foot pocket coupon

## 10. Print and mechanically assemble prototype

- inspect print
- install inserts
- install panels and gaskets
- install drivers
- install cable hardware
- verify seals
- weigh completed enclosure
- test fit in vehicle
- do not begin road use without a positive restraint

## 11. Begin individual-driver measurements

- create conservative DSP measurement presets
- connect one driver at a time
- protect the tweeter with a suitable series capacitor and DSP high-pass
- perform low-level sweeps
- save raw files and setup notes

## 12. Design the passive midrange/tweeter crossover

- measure driver impedance
- import response and impedance into crossover software
- simulate candidate networks
- build a serviceable prototype network
- measure normal and reversed polarity
- revise component values

## 13. Complete full-system DSP tuning

- integrate woofer and upper section
- tune crossover
- adjust delay
- level-match
- equalize
- configure limiting
- evaluate multiple rear-seat positions

---

# 16. Next-Entry Template

Copy this template for future work:

```markdown
## WH-### — Short action title

- **Date:** YYYY-MM-DD
- **Status:** Completed | Partial | Failed | Blocked | Decision
- **Goal:** What this work was intended to accomplish.
- **Work performed:**
  - ...
- **Artifacts changed or created:**
  - `path/to/file`
- **Configuration or materials:**
  - ...
- **Result:**
  - ...
- **Measurements:**
  - ...
- **Problems found:**
  - ...
- **Decision:**
  - ...
- **Next action:**
  - ...
```

## WH-033 — Documentation audit and grounding

- **Date:** 2026-07-18
- **Status:** Completed
- **Task:** Audit PROJECT.md, REQUIREMENTS.md, and WORK_HISTORY.md against the actual repository state and ChatGPT session notes. Update documentation to reflect:
  - Current tweeter selection (D3004/662000, physical verification pending)
  - Distinction between CodeCAD 2-driver baseline and V1 intended 3-driver system
  - Nominal enclosure dimensions vs. STL-derived envelope dimensions
  - Printer build-volume margin warning (415 mm vs. 420 mm Y-axis)
  - Shift from "entirely one-piece" to "primarily one-piece with removable gasketed side-access panel"
  - Preliminary chamber volume analysis (woofer ~12.04 L, midrange ~5.70 L) with notes on pending analysis
  - Keystone 4109 binding-post assembly as provisional selection
  - Removal of "uploaded context" language; grounding in actual repository artifacts
  - Use of Git history for commit dates
- **Changes made:**
  - Updated PROJECT.md: tweeter line, enclosure concept section, current project state, immediate milestone
  - Updated REQUIREMENTS.md: SYS-005 (tweeter), MEC-BASE-001 and -002 (dimensions and printer margin), added MEC-V1-PANEL (removable panel), added MEC-BASE-007 (preliminary chamber volumes), added ELEC-009b (Keystone 4109)
  - Updated WORK_HISTORY.md: removed "uploaded context" language from WH-027 and WH-028, replaced section 12 with complete repository inventory, updated next action language
- **Result:** Documentation is now grounded in repository reality and reflects the current system architecture (3-driver with removable panel path)
- **Next:**
  - Design and implement removable, gasketed side-access panel in CAD
  - Perform detailed chamber volume analysis (especially midrange)

## WH-034 — Define Codex and Claude Code responsibilities

- **Date:** 2026-07-18
- **Status:** Completed
- **Goal:** Document the user's preferred division of labor between ChatGPT Codex and Claude Code.
- **Work performed:**
  - Updated `AGENTS.md` to make Codex the default design and engineering advisor.
  - Updated `.claude/CLAUDE.md` to make Claude Code the default implementation and operations tool.
  - Defined an explicit handoff pattern: Codex supplies goals, constraints, sequence, and acceptance checks; Claude Code implements and reports artifacts, commands, tests, and unresolved issues.
- **Decision:**
  - Codex should normally provide design guidance, best practices, review, and next-step advice.
  - Claude Code should normally write code, run shell commands and tests, modify implementation files, and interface with SolidWorks or Fusion 360.
  - Either tool may work outside its default role when the user explicitly requests it.
- **Tests and measurements:** Documentation-only change; no engineering tests or measurements were required.
- **Current state:** The tool responsibilities are now explicit in both project instruction files. No enclosure design, requirements, or immediate engineering milestone changed.
- **Next action:** Continue with the existing immediate goal: design and validate one removable, gasketed side-access panel.

---

## WH-040 — Fabrication hardware arrived and execution sequence reset

- **Date:** 2026-07-18
- **Status:** Reported; physical inventory pending
- **Goal:** Convert the arrival of fabrication equipment and components into a safe, low-waste execution plan.
- **Newly reported on hand:**
  - 3D printer
  - speakers
  - filament
  - tools
  - additional project-related supplies
- **Confirmed facts:** The user reports that these categories have arrived.
- **Not yet verified:** Exact printer model and configuration; individual driver model numbers and condition; filament polymers and quantities; fastener, insert, gasket, wiring, and measurement-tool inventory.
- **Decision:** Printer commissioning, inventory, and physical dimensional verification now precede additional CAD commitment. The removable side-access panel remains the next CAD feature, but it is no longer the immediate physical task.
- **Plan of attack:**
  1. Inventory and inspect all delivered items; photograph labels or record exact part numbers where useful.
  2. Assemble, update only if required by the manufacturer, calibrate, and safely test the printer.
  3. Print a small calibration object; record filament, nozzle, slicer profile, dimensional result, adhesion, and visible defects.
  4. Measure the physical woofer, midrange, and tweeter mounting geometry and compare it with CAD and datasheets.
  5. Reconfirm the vehicle installation envelope, seat travel, HVAC clearance, cable route, and candidate restraint hard points using simple templates before a large print.
  6. Resolve the provisional material choice and verify the 415 mm model fits the actual usable slicer/bed envelope.
  7. Implement the single removable, gasketed side panel in CAD.
  8. Print focused coupons for driver cutouts, inserts/fasteners, gasket compression, binding posts, PG7 glands, and the Sorbothane pocket.
  9. Revise CAD from coupon results, calculate net chamber volumes, model the woofer alignment, and freeze a V1 print candidate.
  10. Slice and review the full enclosure for orientation, supports, time, material use, collision/clearance, and failure risk before starting it.
- **Safety gates:**
  - Do not power loose drivers at meaningful level without suitable filtering and secure support.
  - Do not use standard PLA as the final road-use structural enclosure.
  - Do not begin occupied-road use until a positive mechanical restraint is designed and validated.
- **Current state:** The project has entered fabrication readiness; no physical inspection, printer calibration, dimensional verification, or test print has yet been recorded.
- **Immediate next action:** Complete the equipment inventory and one documented printer calibration print. Stop before printing enclosure-scale geometry.
- **Open questions:** Exact delivered models/materials, whether the tweeter is physically present, which measurement and impedance tools are available, and which filament is intended for the road-use enclosure.

## WH-041 - Driver datasheets transcribed into hardware reference

- **Date:** 2026-07-18
- **Status:** Completed
- **Goal:** Make the three selected-driver datasheets readable and searchable from the Markdown project documentation.
- **Work performed:**
  - Added `docs/HARDWARE_SPECS.md` with manufacturer T-S parameters, mechanical data, electrical data, power handling, features, enclosure examples, source links, and cautious qualitative readings of the supplied response/impedance curves.
  - Linked the hardware reference from `README.md`.
  - Compared the user transcription with rendered source PDFs.
- **Discrepancies resolved:**
  - Woofer Qes recorded as 0.23 from the rendered PDF rather than the transcribed 0.20.
  - Woofer Cms recorded as 0.85 mm/N from the rendered PDF rather than the transcribed 1.85 mm/N.
  - Midrange Le recorded as 0.11 mH from the rendered PDF rather than the rounded transcription of 0.1 mH.
  - Flagged the `12MU-4851-T00_FRC.png` title/filename mismatch with the actual 12MU/4731T00 driver.
- **Result:** Driver manufacturer data is now available as a repository-native reference while remaining explicitly subordinate to original datasheets and later physical measurements.
- **Design impact:** No architecture or accepted requirement changed. The values continue to support enclosure-volume analysis and a measurement-derived midrange/tweeter crossover near the provisional 2.5 kHz region.
- **Immediate next action:** Unchanged: inventory delivered equipment and complete one documented printer calibration print.

## WH-042 - Correct woofer compliance transcription

- **Date:** 2026-07-18
- **Status:** Correction
- **Problem:** `docs/HARDWARE_SPECS.md` initially recorded the 22W/4851T00 woofer compliance, Cms, as 0.85 mm/N based on a visual reading of the rendered datasheet.
- **Verified correction:** The user rechecked the source and confirmed Cms is 1.85 mm/N.
- **Other checked values:** Woofer Qes remains 0.23, and midrange Le remains 0.11 mH.
- **Change made:** Updated the current hardware reference to Cms = 1.85 mm/N.
- **Design impact:** Any future woofer enclosure model or alignment calculation shall use Cms = 1.85 mm/N unless physical parameter measurement establishes a different value.
- **Immediate next action:** Unchanged: inventory delivered equipment and complete one documented printer calibration print.

---

## WH-043 — Tweeter baffle opening added to enclosure CAD

- **Date:** 2026-07-19
- **Status:** Completed
- **Goal:** Add a tweeter mounting opening to replace the cosmetic NH emblem, enabling integration of the Scan-Speak D3004/662000 tweeter.
- **Changes made to `parts/part.lua`:**
  - Removed `badge_panel()` and `monogram_emblem()` functions
  - Added tweeter parameters:
    - `tweeter_bracket_diameter = 104.25 mm` (provisional based on D3004 mounting bracket spec)
    - `tweeter_center_y = 350 mm` (positioned to fit within 410 mm cabinet length)
    - `tweeter_x_offset = 0` (centered on cabinet width)
  - Added `tweeter_baffle_opening()` function to create tweeter cutout with:
    - Main bracket cutout with raised baffle ring and trim ring
    - Rear relief chamfer (2 mm)
    - Same construction style as woofer and midrange baffles
  - No bolt holes added; user to measure exact locations in SolidWorks
- **Geometry validation:**
  - Tweeter extent: Y = 298 to 402 mm (fits within 0–410 mm cabinet length with 8 mm rear margin)
  - No collision with midrange (Y = 340 mm, rear to ~400 mm)
  - Centered on top face, consistent with other driver placements
- **Generated files (rebuilt successfully):**
  - `generated/part.step` (updated)
  - `generated/part.stl` (updated)
- **Next action:** Measure precise tweeter bolt-hole locations in SolidWorks CAD using the D3004_662000.STEP model, then implement mounting holes.
- **Open questions:** Final X offset and Z positioning (if any tilt needed for acoustic optimization).

---

# 17. Immediate Next Action

Inventory the delivered equipment and complete **one documented printer calibration print** using a low-cost filament appropriate for commissioning.

Record the printer model, nozzle, build surface, slicer/profile, filament type, calibration result, and measured X/Y/Z dimensions. Stop before printing enclosure-scale geometry. The next gate is physical driver and vehicle-envelope verification; the removable service panel remains the next focused CAD revision after those checks.

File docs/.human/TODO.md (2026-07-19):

1. Inventory everything that arrived.
   Record the printer model, nozzle, build plate, filament types, exact speaker model numbers, fasteners, inserts, gasket materials, terminals, wiring, adhesives, and measurement equipment. Inspect the drivers for shipping damage.

2. Commission the printer.
   Follow its manufacturer setup/calibration procedure, then produce one small calibration print. Record the slicer profile, filament, dimensions, adhesion, and visible defects.

3. Verify the physical design inputs.
   Measure the woofer, midrange, and tweeter frames, cutouts, mounting holes, depths, terminals, and gasket faces. Compare those measurements with the CAD and datasheets.

4. Recheck the vehicle envelope.
   Confirm seat travel, HVAC clearance, passenger-foot clearance, cable routing, and potential structural restraint points. The existing 415 mm model length has only 5 mm nominal printer-bed margin.

5. Confirm the prototype material.
   PLA is acceptable for coupons and temporary fit checks, but not the final road-use enclosure. The road-use material needs adequate parked-car temperature resistance.

6. Resume focused CAD work.
   Implement one removable, gasketed side panel. Don’t combine this revision with tweeter, crossover, and binding-post integration.

7. Print feature coupons.
   Test driver cutouts, threaded inserts, gasket compression, panel joints, binding posts, PG7 glands, and the Sorbothane pocket before printing the cabinet.

8. Freeze and review V1.
   Incorporate coupon results, calculate net chamber volumes, model the woofer alignment, confirm slicer fit, and review print time, material consumption, supports, orientation, and late-failure risk.

9. Print and bench-assemble.
   Leak-test and inspect the enclosure before powering drivers or installing it in the vehicle. Occupied-road use must wait for a positive mechanical restraint.

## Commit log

2026-07-15 First iteration
    [12MU-4731T00.STEP, 12MU-4731T00.x_t]
2026-07-15 First prototype
2026-07-15 Correct wire pass-through diameter
2026-07-15 Chamfer inner baffle holes
2026-07-16 Include builds in git repo
    [part.step, part.stl]
2026-07-16 Get the right angles
    [part.step, part.stl]
2026-07-16 Add pics and update readme
    [PG7_CABLE_GLAND.STEP]
2026-07-16 Add tweeter
    [D3004_662000.x_t]
2026-07-16 Organize files
    [12MU-4731T00.STEP, 12MU-4731T00.x_t, D3004_662000.x_t]
2026-07-19 Lower-case .claude folder for consistency
2026-07-19 Add tweeter to cabinet
    [part.step, part.stl]
2026-07-19 Build with tweeter baffle
    [part.step, part.stl]
2026-07-19 make solidworks assembly
